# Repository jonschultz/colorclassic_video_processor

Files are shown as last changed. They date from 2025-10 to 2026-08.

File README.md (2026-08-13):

# colorclassic_video_processor
Project for the reverse-engineering of the Macintosh Color Classic's CRT video processor
# Color Classic Video Processor
#
colorclassic_video_processor is an ongoing reverse‑engineering project to recreate the functionality of the XC1186B video processor IC found on the Macintosh Color Classic analog board by designing a replacement PCB that is pin‑compatible with the XC1186B. The goal is not a circuit‑for‑circuit replica but a practical drop‑in replacement that reproduces the processor’s essential behavior (with some features intentionally simplified or omitted and the possibility of adding new capabilities). A major part of the design philosophy is to make use of discrete components in fully custom circuitry, rather than commercial ICs, as much as possible. This helps to ensure that exact behavior is very well understood and documented, while also avoiding future parts obsolescence. Development has progressed to the point where the vast majority of features have been implemented, enabling a Color Classic to generate all required CRT signals for 640×480 VGA operation on machines that were previously modded for that mode. The horizontal deflection pulse, vertical deflection sawtooth waveform, and RGB pre-amps are some of the major circuit subsystems that have been implemented. With little available documentation on the XC1186B itself, functionality had to be initially infered through a long process of signal measurement, route tracing, enabling/disabling various circuit sections, and reproduction of parts of the analog board's schematic. (See my latest partial analog board schematic [here](https://github.com/jonschultz/colorclassic_video_processor/blob/main/images/CC_analog_video_section_20260513A.pdf)). Much of that work is documented here, albeit most of it after the fact. As of July 2026, multiple revisions of PCBs with hand-assembled components have been tested, including earlier milled PCBs and later vendor-fabricated PCBs. The latest is v4.0.1, which includes minor improvements to the original v4 design, tested with rework applied. If you want to skip a lot of details and go directly to downloading the design and fabrication files, go [here](https://github.com/jonschultz/colorclassic_video_processor/blob/main/fabrication.md).<br><br>

## Current Capabilities (v4)
* Support for 640x480 resolution at 60Hz refresh and 800x600 resolution at 57Hz refresh on VGA-modded Color Classics, or the "standard" 512x384 resolution at 60Hz refresh. Other resolutions, horizontal and vertical frequencies are also likely to work, but haven't been tested.<br>
* Brightness and Contrast adjustment functional by way of MacOS software controls, such as through the "Screen" control panel. Contrast adjustments are also functional by way of the front bezel buttons.<br>
* Large dynamic range adjustment of individual RGB channel gain is available using on-board potentiometers.<br>
* All geometry adjustment functions by way of the Color Classic's analog board rear potentiometers are functional.<br>
* Many of the color adjustment functions by way of the Color Classic's analog board rear potentiometers are currently functional, except for "Green Gain" and "Blue Gain".<br>
* Very high bandwidth RGB preamps on-board, providing very sharp images and exceptional color reproduction.<br><br>

## A Word about Specs and Compatibility
* It's currently difficult to know exactly what voltages or signals are within tolerance for inputs and outputs of the XC1186B. I can only work based on what are assumed nominals generated/received by the Color Classic. However, my hope is that colorclassic_video_processor would also work with other Macintoshes that also use the XC1186B, but I haven't done any testing with those systems, nor measured any of their associated signals/voltages.<br>
* The XC1186B is supplied with 8V and 24V (the latter, albeit, with relatively high output impedance) from the Color Classic's analog board. Like much of the inner workings of the XC1186B, I'm not sure how it uses those supplies internally. The 8V is definitely required to run most, if not all, of the subcircuits. In colorclassic_video_processor, I make use of the 8V for all the supply power, and no use of the 24V. There are multiple reference and supply voltages that I internally derive from the 8V. I've tried to make the circuitry tolerant to some variation and noise on the 8V supply, but it's not completely agnostic to the precise supply voltage. Geometry will vary slightly over the range of at least a few hundred millivolts, which can, of course, be corrected with the usual adjustments. This might be a difference from the behavior of the XC1186B, but again, I'm not sure how its supply voltages are spec'ed. The design is certainly open to the possibility of simple changes that could accomodate a wider supply voltage range or different nominal, if those applications ever arise.<br>
* colorclassic_video_processor will draw from about 600mW to 800mW of power from the 8V supply under normal conditions. This can vary as a function of resolution, brightness, contrast, and other factors.<br>
* All of my testing has been on my "Mystic"-upgraded (performed by me) Color Classic, using an LC575 logic board with 32MB of RAM and 1MB of VRAM. The analog board was modified using the "VGA mod", though I've gone back and forth between the 68V and 84V B+ modifications in order to test both at different times. I've also made modifications to easily switch back and forth between the stock sense line configuration and the VGA configuration, allowing me to test 512x384 resolution to some extent. The vast majority of my testing has been at 640x480 resolution, 60Hz refresh, using 68V for the B+. Quite a lot of work in v4 has gone into supporting a range of resolutions and frequencies, some with more testing than others.<br><br>

## Coming Soon (maybe)
* Possible support for the "Green Gain" and "Blue Gain" analog board potentiometers.<br>
* VGA input and output capability.<br>
* Ability to swap between Contrast or Brightness association with front bezel controls using an on-board physical switch.<br>
* See [Future and Ongoing Work](future.md)<br><br>

#
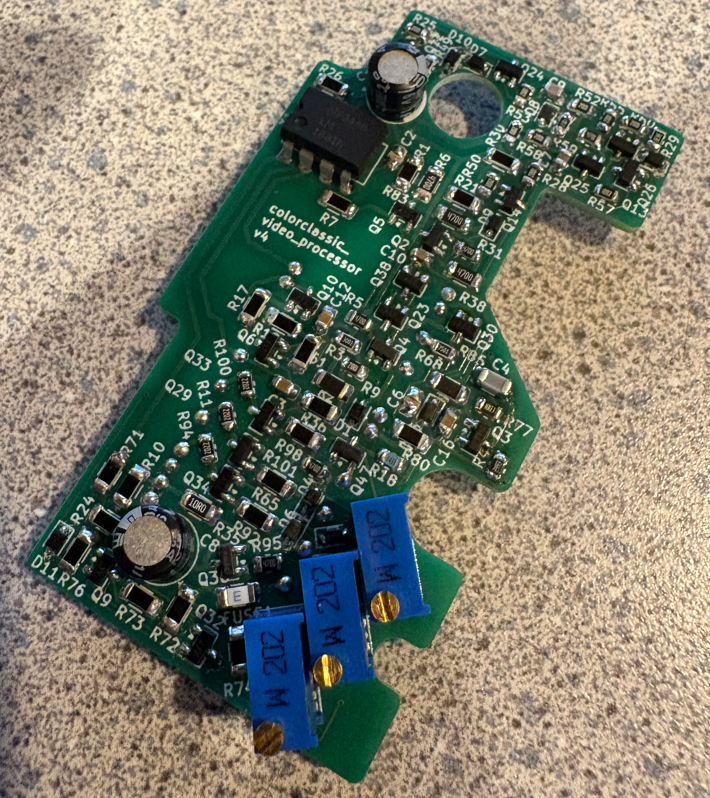
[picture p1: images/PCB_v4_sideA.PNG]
PCB1

<br>
Vendor-fabricated, hand-assembled PCBA. The outline of the PCB is quite unusual, in order maximize board area within the video "cage", while providing clearance to other nearby discrete components.
<br><br><br>
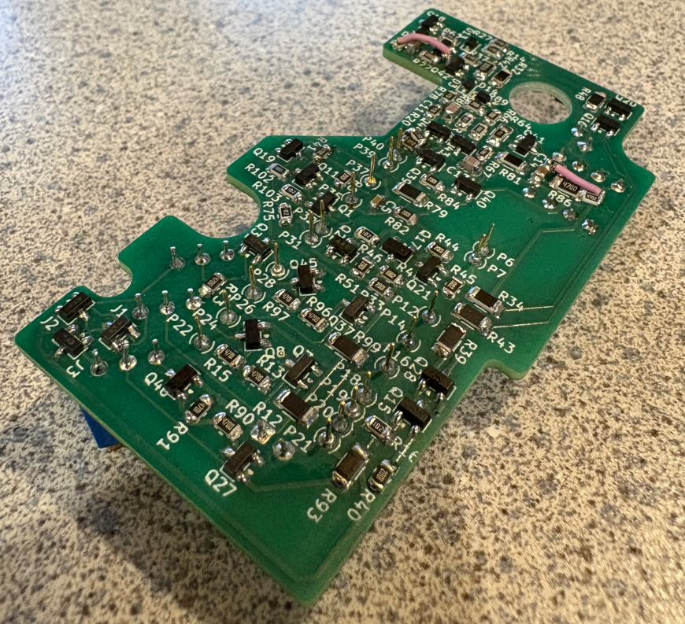
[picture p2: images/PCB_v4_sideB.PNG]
PCB2

<br>
Bottom side of the PCBA, showing pins and additional circuitry. Some rework is visible, bringing the design version from v4 to v4.0.1.
<br><br><br>
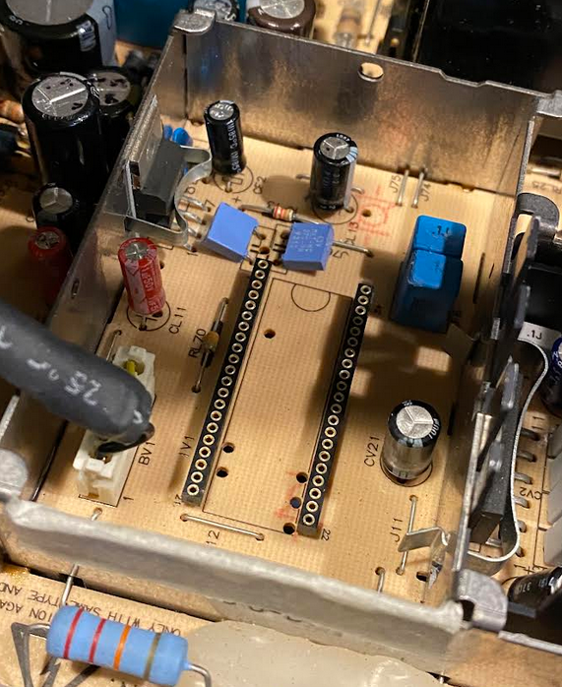
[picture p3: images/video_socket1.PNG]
socket1

<br>
The video "cage" on the analog board, showing the original XC1186B removed and 2x 21 pin sockets (Preci-dip 317-87-121-41-005101) installed for quick installation and removal of the custom PCBA.
<br><br><br>
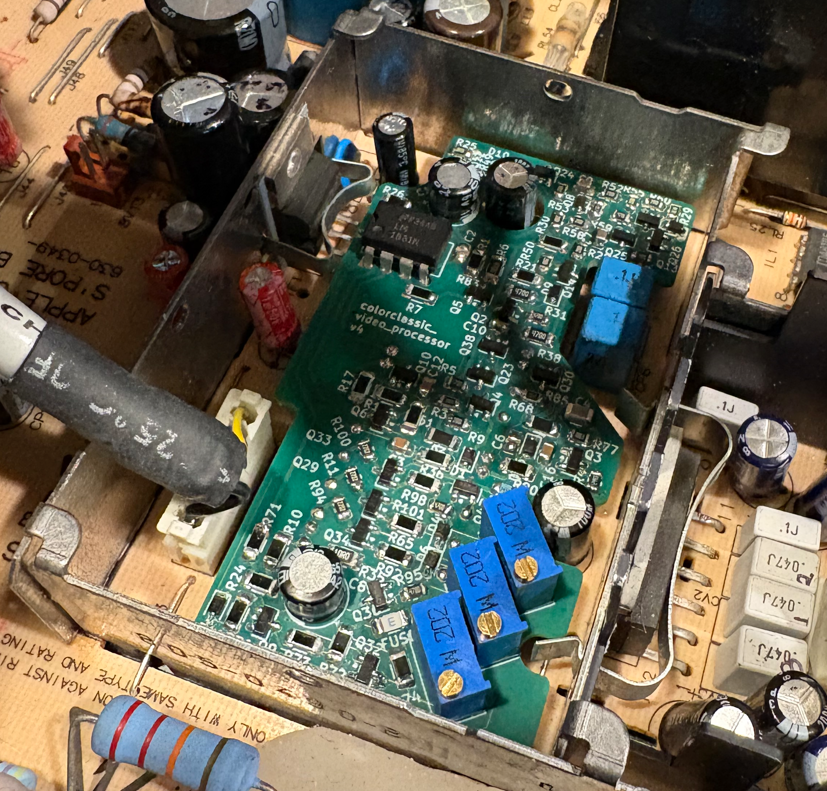
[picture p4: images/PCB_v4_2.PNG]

<br>
The v4 PCBA installed in the sockets.
<br><br><br>
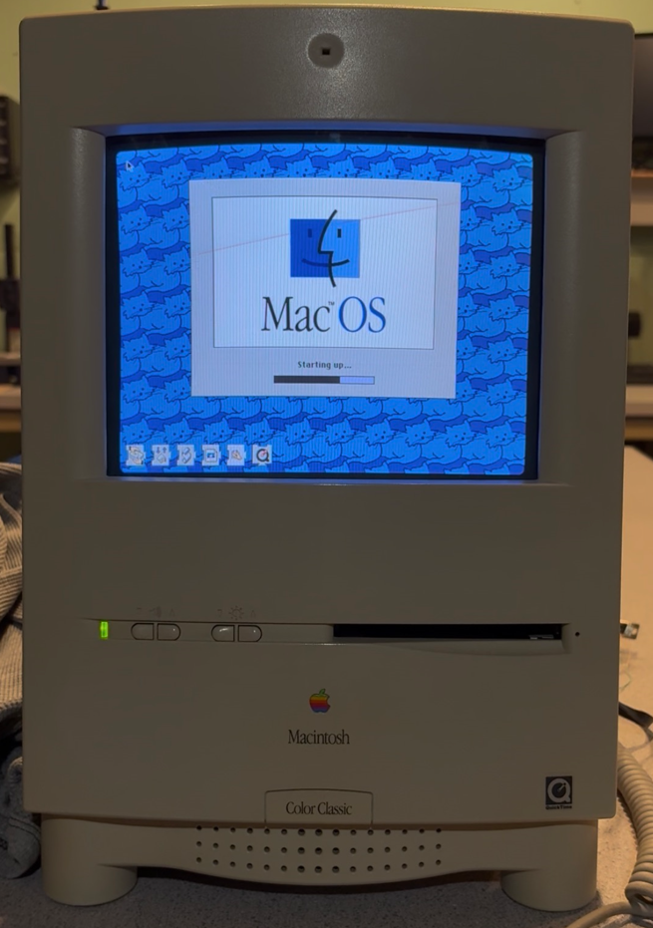
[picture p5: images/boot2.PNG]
boot

<br>
Running with the colorclassic_video_processor, during boot.
<br><br><br>
#
[Image Gallery](gallery.md)
<br>
[Main Schematic and Sub-Circuits](sub_circuits.md)
<br>
[Fabrication Files and Notes](fabrication.md)
<br>
[Installation and Setup](setup.md)
<br>
[Future and Ongoing Work](future.md)
<br>

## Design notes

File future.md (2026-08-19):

# Future and Ongoing Work
* In the spirit of providing more drop-in compatibility, if there is any outside interest in enabling the Blue Gain and Green Gain pots on the analog board (the only two that are currently non-functional with colorclassic_video_processor) I might work to implement it. I doubt that I would eliminate the gain pots that are on-board, since I personally think this is an upgrade due to the large dynamic range and 3-channel independent control. More likely, I would enable the Blue Gain and Green Gain pots to provide a little bit of fine control, in parallel with the full-range control of the onboard pots, similar to I've implemented Sub Contrast.<br><br>

## Development History
* 8/18/2026 - Working on layout of v4.2.0 with on-board connector for VGA output.<br><br>
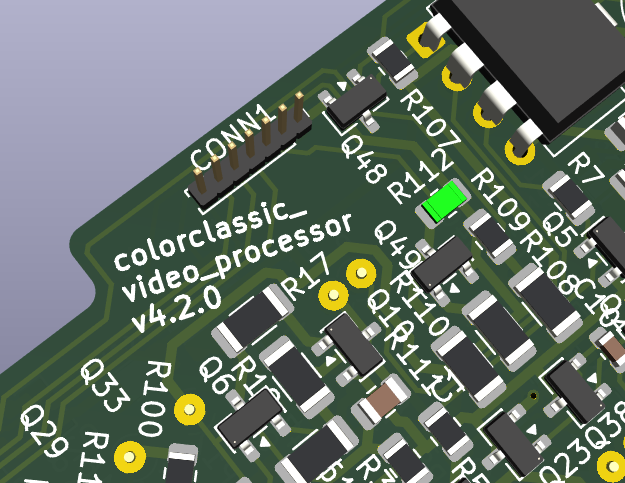
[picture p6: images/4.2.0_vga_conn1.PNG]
vga_conn1
<br><br>
* 8/12/2026 - Proof of concept for VGA output capability demonstrated with design mods and rework on a 4.0 PCB.<br><br>
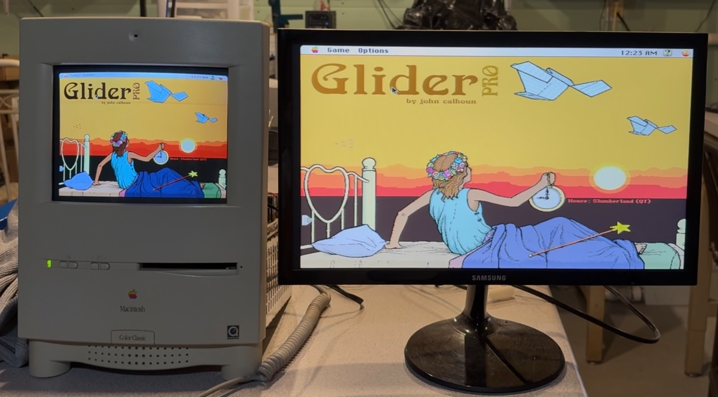
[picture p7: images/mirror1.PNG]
mirror1
<br><br>
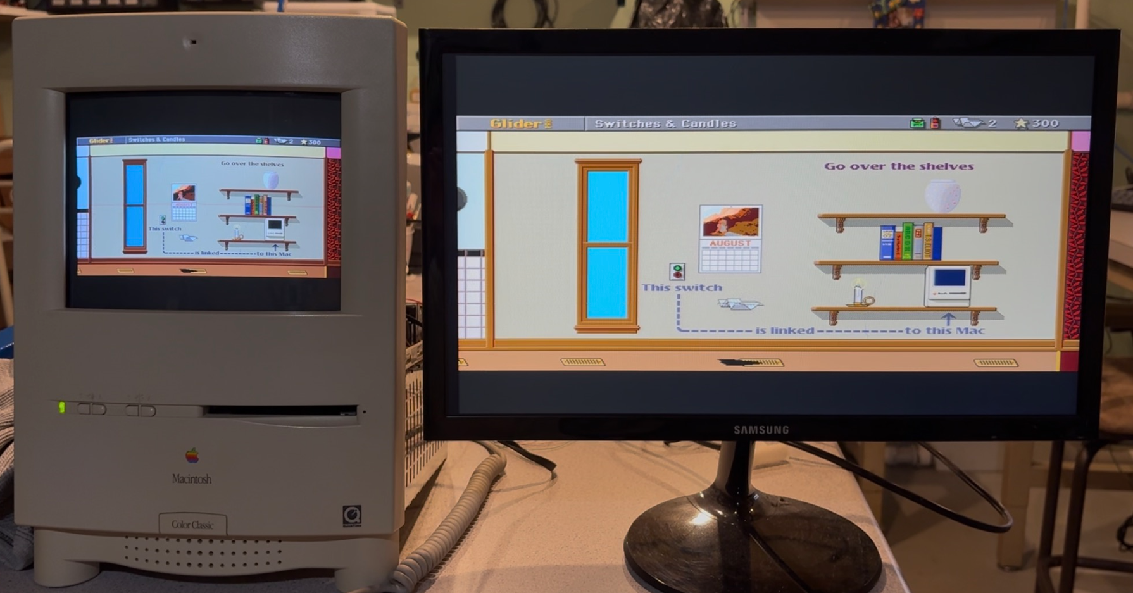
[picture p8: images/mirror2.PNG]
mirror2
<br><br>
* 7/26/2026 - Version 4.0.1 design released publicly.<br><br>
* 7/21/2026 - I've received the v4 PCBs from the fab, and I've got one assembled and running. Performance looks good and prety much identical to the reworked v3 prototype. However, I've already made some small changes to a few component values and some other minor changes in the horizontal section for further reduced temperature sensitivity. I plan to package up the KiCad files, BOM, and Gerbers + drill files for v4.0.1 and post them within the next few days. This will also mean that I'll need to clean up all the other sections of the repo to reflect the latest design. It's a lot of work, but it's coming.<br><br>
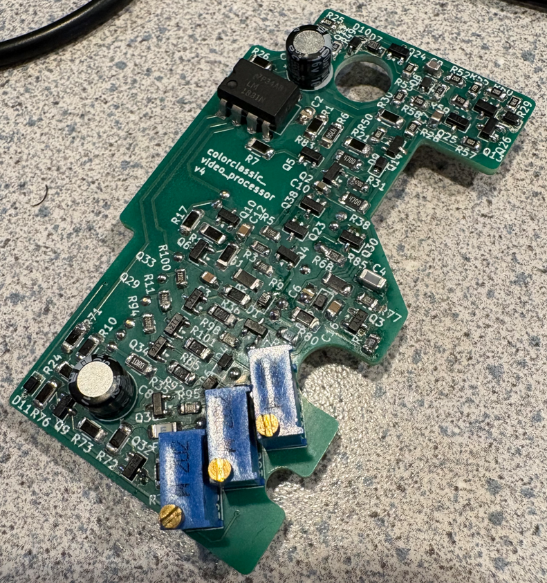
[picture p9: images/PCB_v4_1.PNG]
PCB_v4_1
<br><br>
PCB_v4_2<br><br>
* 7/3/2026 - Completed porting the v4 design to KiCad, and now in the process of getting PCBs made externally. After initial assembly and testing, I plan to update all the documentation and post output files for v4, including Gerbers for PCB fabrication. v4 features will include:<br><br>
    * Better support for various resolutions and timings by normalizing horizontal and vertical adjustment ranges accordingly.<br>
    * PLL-like horizontal timing synchronization for reduced drift and horizontal shift effects across a frame (such as due to pincushion correction). Eliminates the need for a special connection to the TDA8145.<br>
    * Eliminates the additional coarse vertical adjusment potentiometer.<br>
    * Cleaner routing using standard PCBA design rules.<br><br>
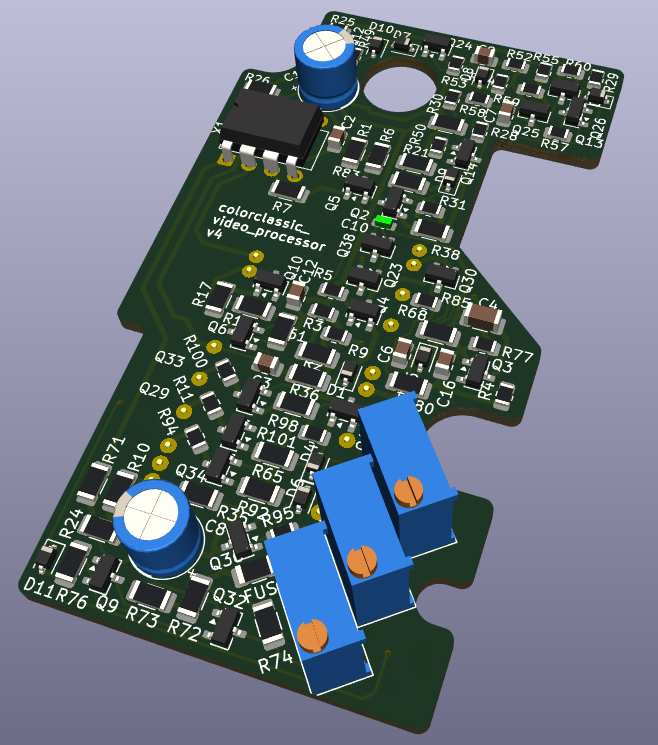
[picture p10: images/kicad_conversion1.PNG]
kicad
<br><br>
* 6/27/2026 - v4 design is complete and I'm in the process of converting the project over to KiCad. The next design and output files that I post here will hopefully be output files from KiCad for easy PCBA fabrication.<br><br>
* 6/20/2026 - Further improvements to the phase correction in the horizontal circuitry have been prototyped and are working well. It has improved capability to detect the horizontal frequency and scale certain signals accordingly, requiring even less adjustment when switching resolutions. I've also implemented similar scaling in the vertical circuitry, though there's still some work to be done there for v4.<br><br>
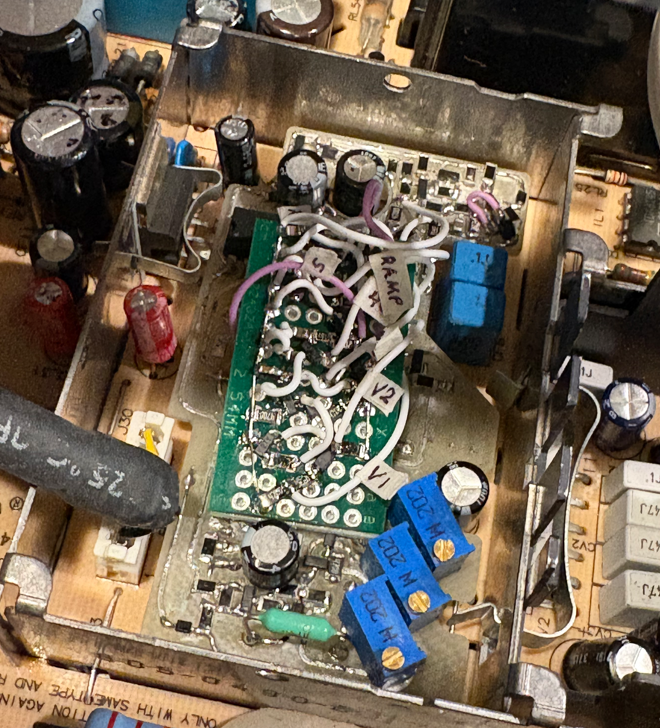
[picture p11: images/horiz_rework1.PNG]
rework
<br>
v3 PCBA with rework and additional proto-board to experiment with v4 changes.<br><br>
* 6/6/2026 - I've prototyped changes to the horizontal circuitry on v3 to measure and regulate the phase of the horizontal drive pulse relative to the flyback pulse, providing PLL-like functionality. This goes beyond even the function mentioned above, removing many of the horizontal shift drift effects. It also makes the system even more agnostic to various resolutions and associated horizontal frequencies, and eliminates the need for a signal from the TDA8145 for "warp compensation". I'm working on more testing and optimization. I hope to have a v4 layout done in the next couple of weeks.<br><br>
* As of 5/26/2026, I've been experimenting with design changes and rework of the published v3 design to change the horizontal drive timing architecture. I have it basically working with timing referenced to the current scanline's HSYNC pulse, while also controlling the duty cycle more accurately. This makes the system much more tolerant of changes to the horizontal frequency, enabling 512x384, 640x480, and 800x600, with only some adjustment of the Horizontal Shift ("HS") potentiometer.<br><br>

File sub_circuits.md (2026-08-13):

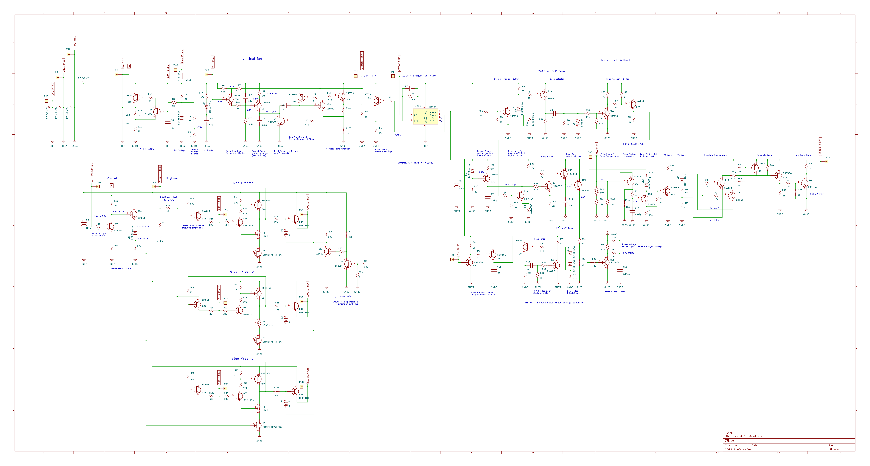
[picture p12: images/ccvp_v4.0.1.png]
schem_4.0.1

#
Change Log:
* 7/26/2026 - Updated to the v4 design (v4.0.1 design and output files provided as first release), including lots of improvements and a true EDA-based design using KiCad.<br><br>
* 5/24/2026 - Changed R54 value to 1k and changed D8 to Schottky. Both changes were required to achieve faster HSYNC edge detection at higher resolutions, with more support coming in the future.<br><br>
* 5/17/2026 - Updated some references to component values below. Clarified description of capabilities for RGB gain control.<br><br>
* 5/13/2026 - Update to schematic 20260513A. Change name of "Skew Compensation" to "Warp Compensation" and make it a standard section of the circuitry, now that it has been implemented in the latest revision. Incorporate SMMBFJ177LT1G JFETs into RGB preamps as part of dynamic gain for contrast adjustment. Add level shift circuit section for using the contrast adjustment voltage at Pin 19 to drive JFETs.<br><br>
* 4/5/2026 - Update to schematic 20260405A. Incorporates capacitive coupling between vertical deflection accumulator and amplifier and associated output-referenced clamp. Coarse adjustment pot for vertical size removed and replaced with fixed resistors. V1 of horizontal section changed to fixed voltage with Schottky diode. Ramp buffer converted to NPN follower for improved thermal stability (always far from saturation region). In RGB section, introduced output-referenced active clamp with simplified brightness supply. VHF/UHF BJTs incorporated into amps. Created unity-gain buffer section with pulldown for sync-tip insertion. Minor value tuning to accomodate reversion to original CC flyback (157-0146) and associated change of B+ from 84V to 68V.<br><br>

<br><br>
# General Notes
* Unless specificed for another particular component, any reference to a "Pin" position is with respect to the XC1186B's original pinout, and as such, the pinout of colorclassic_video_processor.<br><br>
* I've taken some effort to label components uniquely and clearly, but there's always the possibility for mistakes. The reference designator numbering is somewhat random, as automatic labeling was at play while the design evolved over time. Many components were deleted and new ones emerged, with numbers being recycled in a somewhat disorganized way.<br><br>
* A parts BOM is provided in the [Fabrication Files and Notes](fabrication.md) section. Some specific part numbers are provided in the schematic above, but many aren't. Some common parts, like resistors, will only be given rough specs and package type rather than a specific manufacturer's part number.<br><br>
* I've added a "Condsiderations" section for each circuit category below, mainly to help those interested in building on this design or making changes. These sections are intended to explain some of my design intent and some possibly important things about the CC's electronics in general. My understanding is certainly not 100% comprehensive, but I hope others find this information useful.<br><br>
<br><br>

# Horizontal Section
<br>
The high-level function of the horizontal section is to take the composite sync signal provided on the Color Classic analog board ("AB"), extract a horizontal sync signal, and then use that to generate the horizontal deflection pulse within the required range of duty cycle. The horizontal deflection pulse is used to ultimately pulse the horizontal output transistor on the AB.
<br><br>

## Signal Chain:
* The LM1881 IC is used to provide a DC-coupled, approx 0-6V composite sync ("CSYNC") signal, using the AB's AC-coupled CSYNC singal as input. The LM1881 provides other functions that will be described in later sections. But here, the "copy" of the CSYNC signal is useful as a low-ouptut impedance input to the horizontal circuitry. The CSYNC falling edge represents the start of a scanline.<br><br>
* CSYNC pulls a simple voltage regulator of two 3.3V Zener diodes to ground when high with a BJT inverter, conversely producing 6.6V at the falling edge.<br><br>
* The 6.6V pulse is buffered and drives a simple edge detector comprised of an RC network. A quickly decaying exponential pulse results (about 1μs in duration), independent of the duty cycle of the CSYNC input. This allows the circuity to generate all pulses nearly equally in amplitude and duration, whether the input pulse is at the start of the scanline or during the vertical sync period when the duty cycle is larger.<br><br>
* Two BJTs are used to "clean" and buffer the pulse into a more digital signal. In effect, this generates a horizontal sync ("HSYNC") signal.<br><br>
* Independently, a BJT current source (referenced to the 8V rail) linearly charges a 0.047uF accumulator capacitor to produce a linear voltage ramp.<br><br>
* The HSYNC pulse is then used to reset the accumulator to 1 Vbe (set by a biased diode D9) at the horizontal frequency at the start of every scanline. The resulting sawtooth waveform is buffered by an NPN BJT, with an output voltage between 0.6V and 4V.<br><br>
* Two reference voltages ("V1" and "V2") are generated through a complex timing network, which is new for v4, described further below. Threshold comparator BJTs are used to trigger switching when the accumulator sawtooth crosses the V1 and V2 voltages, corresponding to the falling and rising edges of the horizontal drive pulse that is ultimately provided as an output on Pin 32.<br><br>
* The switching of the threshold logic BJTs is inverted and buffered by another switching BJT. This signal is applied to Pin 32, which drives a MOSFET on the AB and ultimately drives the rest of the horizontal section. The timing of the rising edge of this final output pulse controls the phase of the horizontal scan in relation to all other signals (especially the video signals). This edge should occur about 28μs after the falling edge of CSYNC in order to have a well-centered image (at 31.5kHz horizontal scan frequency).<br><br>
* As mentioned above, the V1 and V2 voltages a generated by timing network that receives feedback from the flyback pulse on Pin 35. The flyback pulse first triggers the charging of C13. A separate circuit sub-section triggers off the previously described sawtooth waveform at roughly halfway through the scanline, using the peak value of the sawtooth for normalization (which can vary depending on image resolution and horizontal frequency). This section subsequently dicharges C13. The voltage on C13, therefore, provides a roughly 50% duty cycle digital pulse representing the phase relationship between the flyback pulse (representing the true start of a scanline) and a half-scanline delay from the horizontal sync pulse. Subsequent filtering to produce a "phase voltage" and comparison to a reference voltage provided by way of "HS" Pin 40 is used as an input to modulate "V2" (and the derived "V1"). In effect, the circuitry provides PLL-like timing feedback to maintain the phase relationship between the horizontal sync and the actual scanline start time. This automatically corrects for phase changes in the downstream horizontal deflection circuitry on a line-by-line basis, such as from width modulation handled by the TDA8145. As such, there is no need for other correction circuitry tied to the TDA8145, as was implemented in V3.
<br><br><br>

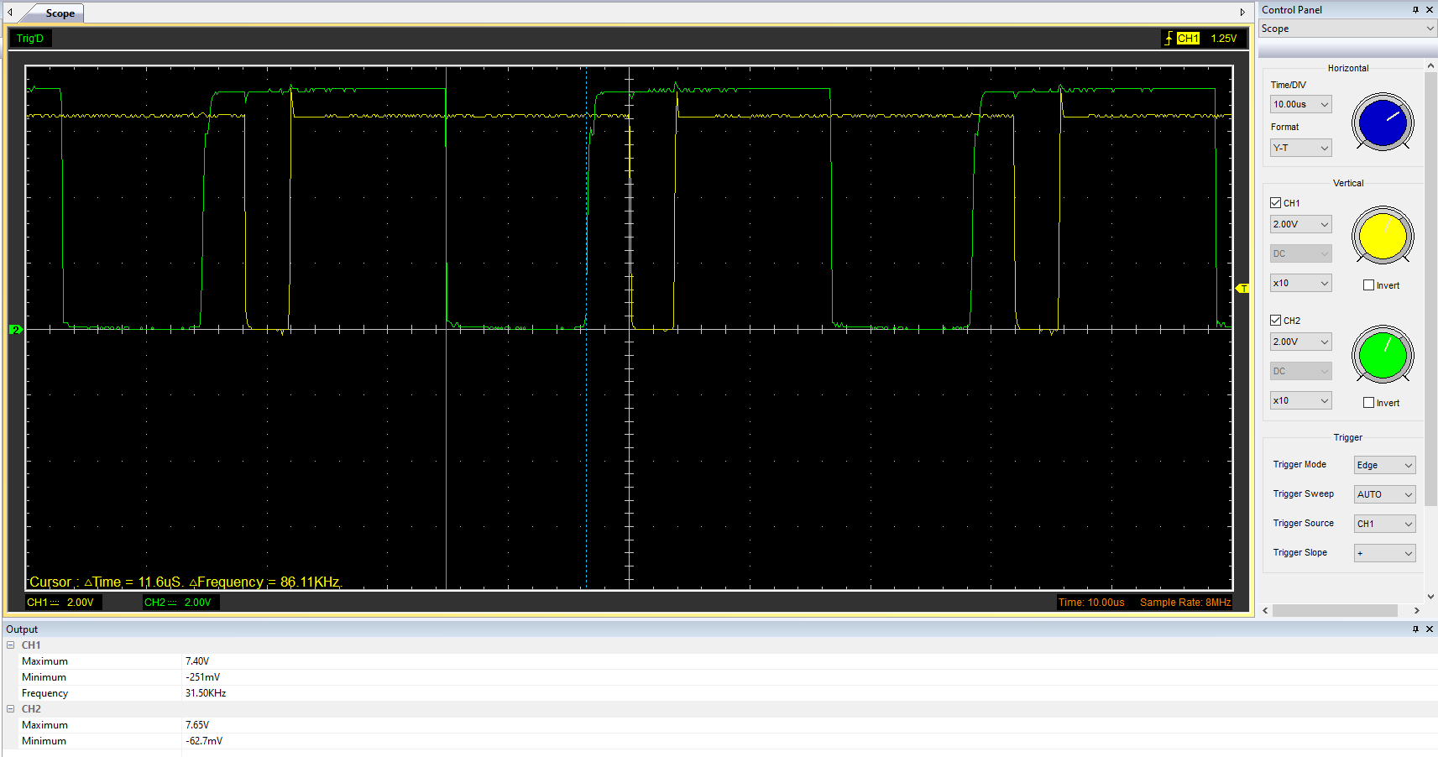
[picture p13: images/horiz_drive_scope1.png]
horiz

<br>
Scope shot showing the composite sync signal from pin 1 of the LM1881 (Channel 1) and the horizontal drive output signal (Channel 2) at Pin 32. The positive edge of the drive signal starts the cycle of tracing the next horizontal line as it drives the downstream circuitry on the AB. For a well centered image, this edge is roughly 28 microseconds after the negative edge of the previous composite sync pulse. The negative edge of the horizontal drive signal is less critical to the general timing, but is typically about 11-12 microseconds (as shown by the vertical cursors).
<br><br><br>

## Considerations:
* Like the other sub-circuits, the supply voltage is 8V from the Pin 22 position. This appears to be the main rail for powering the XCll86B, though there appear to be other supply voltages (more on that later). The grounding approach for all the sub-circuits is especially important for avoiding video artifacts. Through experimentation, I've found that associating all the horizontal circuitry with Pin 31 ground (#3 in my schematic) is best, which is physically closest to the pins associated with the horizontal section.<br><br>
* A lot of trial and error was employeed to make the timing stable, especially with respect to temperature. Use of accumulator capacitors with low temperature sensitivity is particularly important, as well as using a small voltage rise. The high linearity and lower temperature sensitivity outweigh any SNR benefit in this regime. I've also tried to match complementary pairs of BJTs or diode where possible to null the effects of junction voltage drift. A tiny bit of temperature sensitivity remains, which I've nulled with use of thermistor TH1 as part of the "HS" divider network.<br><br>
* A capacitor was originally connected in parallel with R45, in order to slow the discharge of the base voltage on Q21. The purpose of this was to avoid a short secondary pulse at the output when the sawtooth waveform falls sharply on the negative edge, switching the threshold circuitry in reverse order. These events happen on the time scale of a few microseconds, and as such, Q21 is discharges its base slowly enough without an additional discrete cap. The use of a relatively large resistance on R45 provides some discharge function (necessary to "reset" the circuitry quickly engough for the next cycle), but is slow enough to avoid generating the secondary pulse.<br><br>
* All BJTs used in this section are (S)S8050s (NPN) or (S)S8550s (PNP), unless otherwise noted. These are well matched BJTs that are reasonably fast for this application and have good gain. The final output transistor at Q22 requires a little more collector current handling, and I've opted for FMMT449. This part is also used for the discharge transistor for the accumulator.<br><br>
<br><br><br>

# Vertical Section
<br>
The vertical section's main function is to generate a sawtooth waveform that represents the beam displacement from the top of the display to the bottom, with the lowest voltage value representing the start of the scan at the top. This waveform drives the TDA8172, which is a sort of high-power opamp that directly drives the vertical deflection coil. Other sections of the AB also make use of the vertical deflection waveform, as discussed below. From probing the output of the original XC1186B, it was found that the vertical deflection sawtooth ranges from about 1.5V to 5.4V, with a high degree of linearity.
<br><br>

## Signal Chain:
* The LM1881 IC is used to generate a VSYNC signal, extracted from the AC-coupled CSYNC provided by the AB on the Pin 6 position.<br><br>
* Independently, a simple current source and a 0.47 microfarad accumulator capacitor generate a linear voltage rise of about 1V over a single 60 Hz refresh period. The exact current is adjustable by way of the AB's "VH" potentiometer, which is input on the Pin 39 position. VH forms a voltage divider with a 3.3V Zener-regulated supply, the output of which modulates a level shifter that drives the BJT current source.<br><br>
* The voltage on the accumulator capacitor is reset to ground with a BJT that's driven by the VSYNC signal as a triggering pulse. The video processor's 5V supply piggybacks off this regulator's Zener reference, and provides 5V output on the Pin 7 position.<br><br>
* The amplitude of the accumulator capacitor is intentionally kept low (1V as described above) in order to maintain high linearity of voltage with respect to time.<br><br>
* The final output sawtooth waveform requires a non-zero trough voltage of about 1.3V, though there is some tolerance on this. In order to achieve this voltage (corresponding to the "reset" state of the circuit) and produce a sufficient offset for the subsequent amplifier stage (described below), capacitive coupling between the accumulator and amplifier stage is employed with clamping. The clamping implementation measures the output of the amplifier stage during the trough with a BJT, using a simple 1.95V voltage divider (from the 3.3V supply) as the supply and reference voltage. This allows it to recharge the coupling cap to a relatively small voltage precisely, nulling out drift in the Vbe of the amplifier stage while requiring very little current from the 1.95V supply.<br><br>
* The accumulator's signal is then amplified by a dual-BJT feedback amplifier with a gain of 4x. The output is fed back to a comparator BJT Q30, which modulates the input to the accumulator current source to maintain a maximum peak value for the sawtooth waveform. This is referenced against a voltage derived from "VH" Pin 39, providing very stable waveform amplitude. The peak to peak values are approximately 1.3V to 5.4V, as required as input to the downstream circuitry of the AB, including the TDA8172.<br>
<br><br><br>

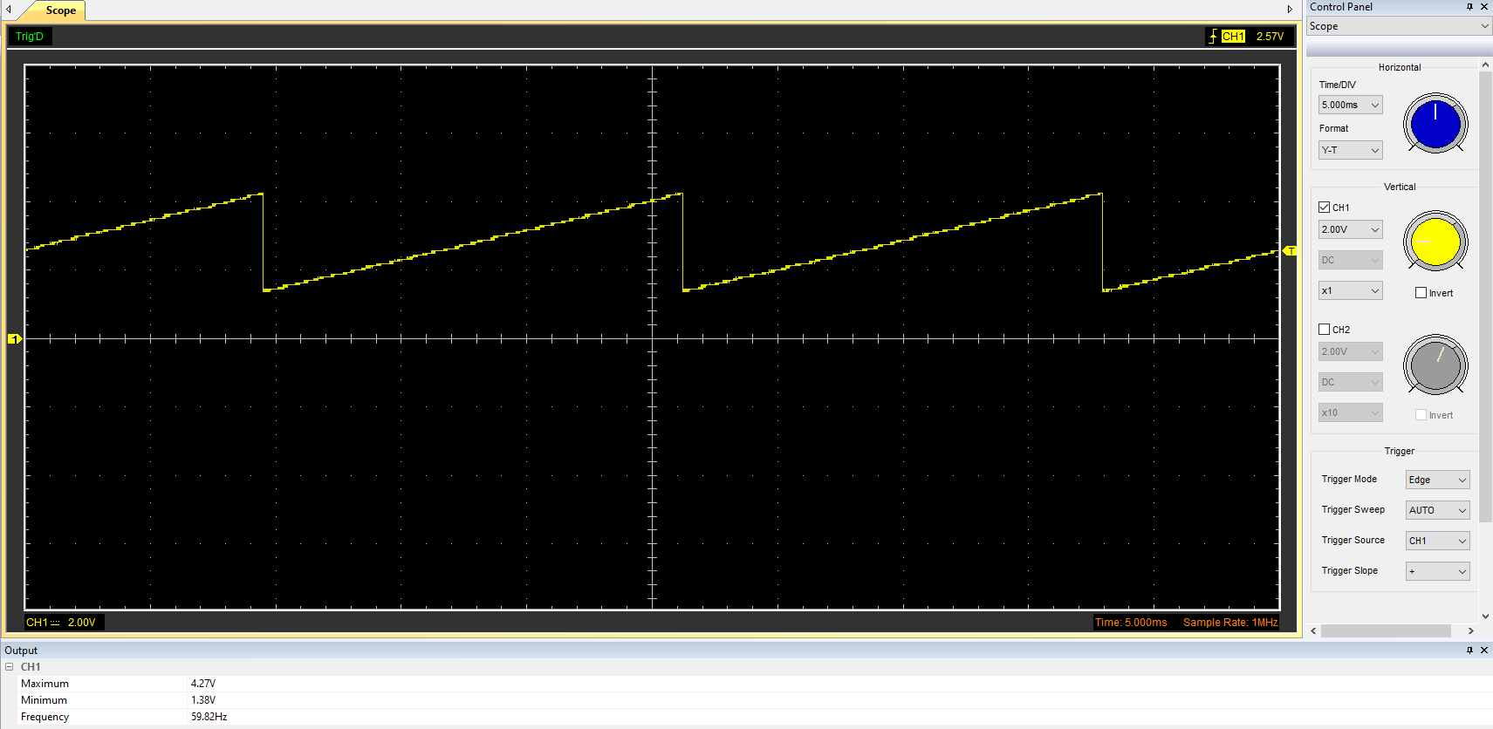
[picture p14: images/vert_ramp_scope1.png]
vert

<br>
Scope shot showing the vertical ramp signal generated on Pin 37.
<br><br><br>

## Considerations:
* As mentioned, keeping the accumulator amplitude low was important to maintain good linearity and temperature stability. D3 in the level shifter also helps in this regard by matching and nulling out much of the thermal drift in Vbe on Q3. Having a reliable and stable current source is important for this implementation.<br><br>
* The exact value of the trough of the vertical sawtooth waveform is not especially critical, as the output of TDA8172 is capacitively coupled to the vertical deflection coil, though it's important to not saturate the voltage on peak of the waveform. DC is restored separately at the TDA8172, and the vertical shift, "VS", potentiometer and associated circuitry on the AB contribute to this function. As such, VS still works as it normally would. As mentioned, other parts of the AB use the vertical sawtooth as a signal representing the vertical beam position, notably the TDA8145, which accepts it as input for pincushion correction (horizontal scaling as function of vertical position). Changes in the DC level ultimately result in modulation of the keystone geometry. The TDA8145 can account for this and add its own DC reference by way of the keystone correction potentiometer on the rear of the AB. A trough voltage of around 1.3V was empirically found to be suitable for all functions.<br><br>
* Like in the horizontal section, using the appropriate ground connections is important. I'm using a mix of Pin 31 and Pin 12 ground connections on the prototype PCB. It turned out to be a fortunate choice, as these two are nearly equivalent, being in very close connection on the AB and seemingly associated with the original XC1186B's vertical functions. Video artifacts can result if the Pin 21 ground is instead utilized in the vertical circuitry.<br><br>
* The 5V supply in the vertical section leverages the nearby 3.3V Zener supply as a reference, multiplying it (minus the Vbe of the input BJT) with a 2x gain to achieve ~5.4V. This was found to be slightly better performing that than a nominal 5.0V, possibly because the TDA8172 uses the 5V rail as a reference voltage. Shifting the reference slightly higher than the peak voltage of the vertical sawtooth waveform prevents the appearence of some geometry artifacts at the bottom of the vertical scan. The 5V rail is used in multiple locations throughout the video circuitry, so it's an important supply. Stability is especially important for the TDA8172, as fast fluctuations result in a visible "bounce" in the vertical size of the image as the TDA8172 amplifier settles to a new equilibrium. In an earlier design, small changes in the 3.3V supply induced by fluctuations in the 8V rail caused significant bounce, as the quick step-like changes in the 5V rail create ringing in the TDA8172 ouptut. Quick changes in image brightness are especially prone to causing such fluctuations in the 8V rail. A simple fix was to decouple the 5V supply from the 3.3V reference with a long-time constant RC filter. Here, a 22k resistor and 10uF capacitor help significant to reduce the slew rate of the 5V output in response to step changes in the 3.3V reference, allowing the TDA8172 to equilibrate faster than the change in reference voltage. Fortunately, the actual DC value of the 5V rail plays a much less significant role in the TDA8172 output, making it tolerant to such slow but stable changes.<br><br>
* Like in the horizontal section, all transistors are either (S)S8050s or (S)S8550s, except in case of Q4, which requires especially high collector current capability for discharge. Again, I've opted for FMMT449.<br>
<br><br><br>

# RGB Preamp Section
<br>
Another major function of the XC1186B is to take the low-amplitude, capacitively-coupled RGB signals from the logic board (brought in on connector BV1), add offset for brightness control, amplify them (incorporating contrast control), add sync-tips, and deliver the output to the downstream cathode amplifiers. Interaction with the other sub-functions of XC1186B seems to be fairly limited, with the exception of sync-tip insertion driven by the timing of the sync signals. My implementation is fairly straightforward, making use of dual-transistor class-A amplifiers for each color channel, though the choice of biasing resistors and BJTs was important to provide high bandwidth for crisp image production. There are some nuances in the clamping/brightness circuitry, as well as the sync-tip insertion circuitry, discussed below.
<br><br>

## Signal Chain:
* RGB signals are brought in from Pins 14,16,18, with capacitive coupling and 75Ohm termination provided right on the AB prior to connections at the XC1186B pins. These connections are made to both the amplifier stage and to brightness-control/clamp circuitry, described below.<br><br>
* The amplifier stage for each channel is comprised of an NPN input BJT and PNP output BJT. These are high-speed VHF/UHF BJTs, part numbers MMBTH10L and MMBTH81. A 4.7K pull-up resistor at the base-emitter connection of the PNP greatly improves speed (reducing image smear) by discharging the PNP's base quickly on falling signals, at the cost of a small reduction in the effective gain. The resistor divider on the output, which currently includes 2k trimmer pots on the PCB, determines the amplifier gain (effectively, the image contrast), with a range of about 1x to 5x.<br><br>
* The output of the amplifier stage feeds back to a PNP BJT for active clamping of the capacitively coupled input, as mentioned above. The BJT effectitvely compares the minimum output value (during black-level display) against a reference voltage that also serves as a supply for the clamp. The reference voltage is a divided-down version of the brightness signal itself, provided on Pin 20, with a range of about 1.9V to 2.7V. The brightness signal can be modulated by the logic board, via the Color Classic's brightness control in the "Screen" Control Panel, in addition to other software-controlled interfaces. By measuring against the amplifier output, the clamping circuitry charges the coupling cap to the appropriate level on each scanline, independent of the amplifier gain or other offsets. It's especially good at nulling the drift in the input BJT's Vbe offset and its associated amplified offset, which can be quite large. Charging the coupling cap requires very little current, as as such, the upstream brightness supply does not require additional buffering.<br><br>
* The amplifier output is "lightly" coupled to the downstream circuitry by way of a 470 Ohm resistor. Downstream of it is another MMBTH10L, acting as a simple unity-gain buffer. The base input of this buffer also serves as a node to pull down during sync-tip insertion, without excessively loading or affecting the amplifier stage. The sync-tips are zero-voltage pulses that match the timing and duration of the CSYNC signal, and are used in the downstream cathode drive circuitry for DC restoration. In effect, they serve as a fixed reference voltage to the black level set by the brightness/clamp circuitry. A cascade of two BJT inverters is used to condition the CSYNC signal from the LM1881, which pulls down the unity-gain buffer's base low during the sync pulse period. A single set of inverters services all three color channels, isolating the output of each associated buffer through individual Schottky diodes.<br>
<br><br><br>

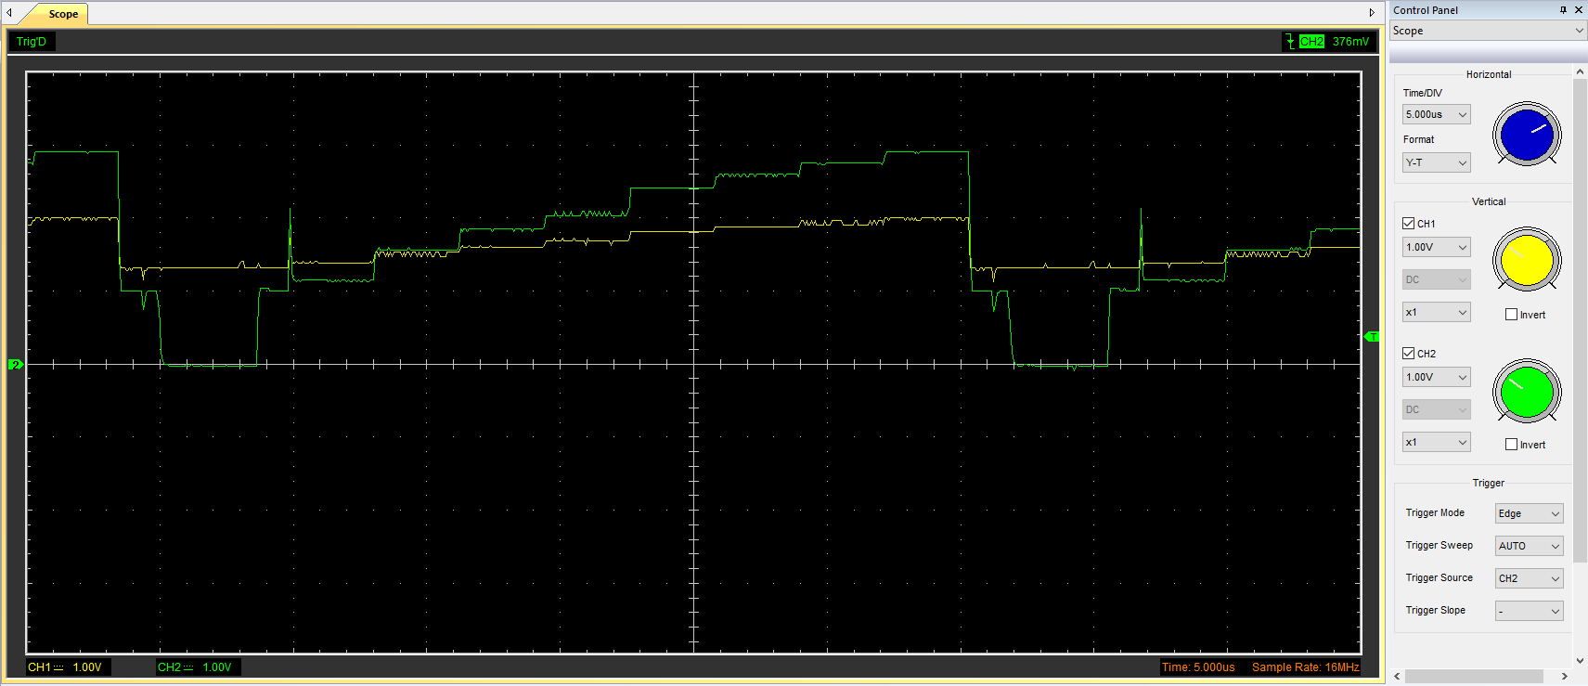
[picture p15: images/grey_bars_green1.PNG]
bars

<br>
Scope shot showing green channel input (Channel 1) at Pin 16 and green channel output (Channel 2) at Pin 26, while displaying a grey bar pattern and with brightness and gain (contrast) optimized for picture quality. The signal input has a range from about 1.3V to 2.0V, and the output is from about 1.0 (black level) to 2.9V, representing a gain of about 2.7x. Note the sync tips in the output signal that fall to 0V.
<br><br><br>

## Considerations:
* The 2k pots on the PCB offer direct control of the image contrast for each channel, but are not ideal solutions for a few reason. One is that they are not readily accessible with the RF cage in place, making casual fine adjustment impractical. Another problem is that the gain range is quite large, and it might be initially difficult to find the ideal contrast (in conjunction with optimal brightness, G2 setting, background, etc). In practice, using 2.8x as a starting gain value seems about optimal (with ".._POT_LO" equal to about 450 to 600 Ohms). See the "Installation and Setup" section for more details. While there is an overall gain control that is adjustable thorugh the Sub Contrast pot on the rear of the AB and through the Screen control panel, the Green Gain and Blue Gain controls on the rear of the AB are not yet functional. These are currently (with the Version 4 design) the only two rear controls that are non-functional.<br><br>
* The value of the coupling resistors R23, R95, and R101 between the amplifier stage and the buffer stage, was chosen as a sort of compromise. Larger values allow the sync-tip insertion circuity to more easily pull down the signal without loading the amplifier's output, but it would create a significant voltage drop between the two stages. The output of the entire RGB section drives 330 Ohm termination resistors (RV7, RV8, and RV9 on the AB), requiring up to about 13mA of current for bright parts of the image. Assuming the current into the buffer stage is about 1% of that, the 470 Ohm coupling resistor has about 63mV of voltage drop. This is not an insignficant drop as it is, and increasing the resistor's value would only add further signal attentuation. However, smaller values would present more of a current load during sync-tip insertion, loading the amplifier while possibly affecting the clamping circuitry.<br><br>
* Schottky diodes were chosen for the isolation of the sync-tip pulldown due to their low forward voltage-drop. This brings the sync-tip level very close to zero, but not quite. Other implementations could provide an improvement, but with higher part count or complexity, such as by utilizing individual pulldown BJTs (Q32) for each channel. Another consideration for the use of Schottkys is that, while they are quite fast, they do have a small capacitance that requires discharge to fully turn them off. The 22k resistor at R74 was found to be optimal to bring the Schottkys' cathodes high after each sync-tip without excessively loading Q32.<br><br>
* In general, the RBG circuitry is fairly sensitive to biasing and particular values of components. The bandwidth needs to be quite high (~100 MHz or higher), requiring fast BJTs and quick charge/discharge of parasitic capacitances. Signal cleanliness is also extremely important, including proper grounding and use of the specified AB ground pins. Generally speaking, any artifacts in the RBG signals are readily visible in the displayed image. A lot of trial and error and analysis of the RGB circuitry has been done to optimize performance. Qualitativley, I think my pre-amp design is quite good, possibly providing better performance and higher bandwidth than those of the XC1186B.<br>
<br><br><br>

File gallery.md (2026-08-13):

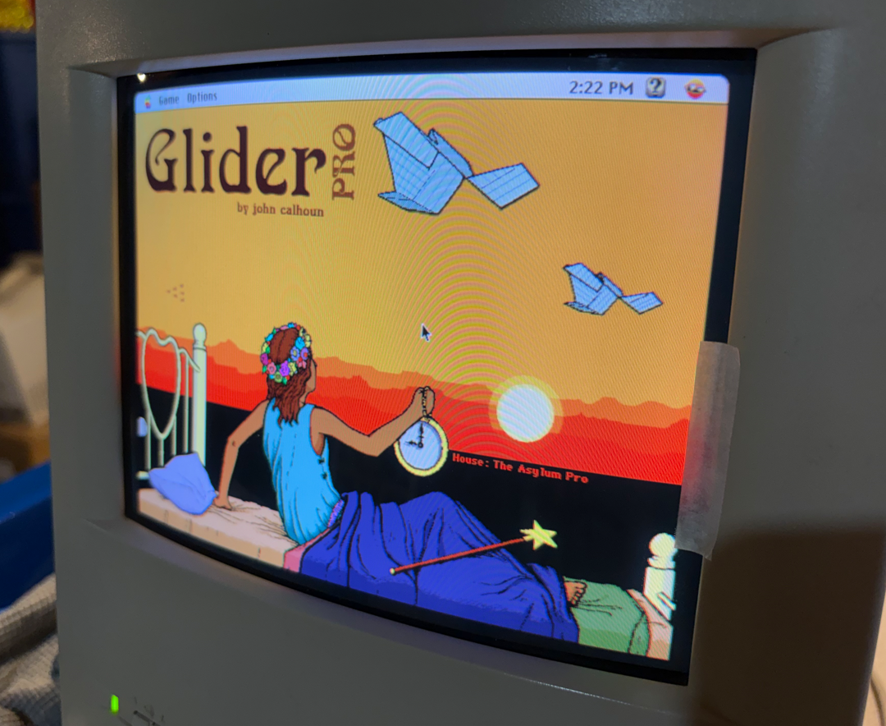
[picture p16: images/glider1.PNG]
glider1

<br>
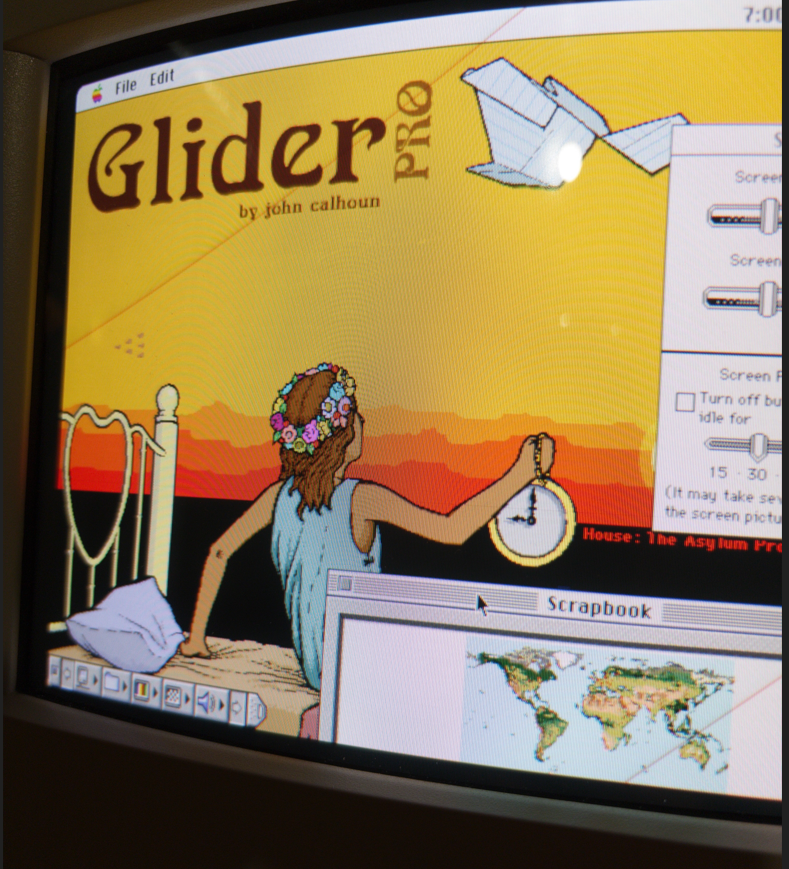
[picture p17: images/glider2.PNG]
glider2

<br>
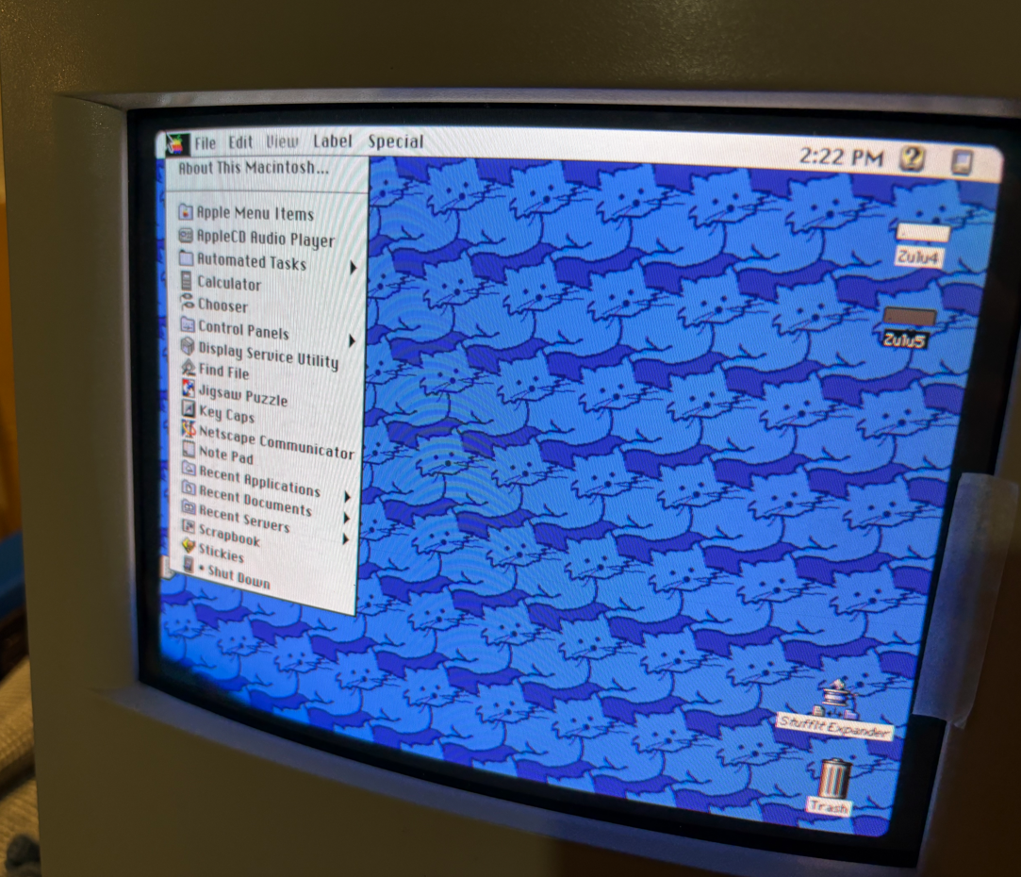
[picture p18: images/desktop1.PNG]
desktop

<br>
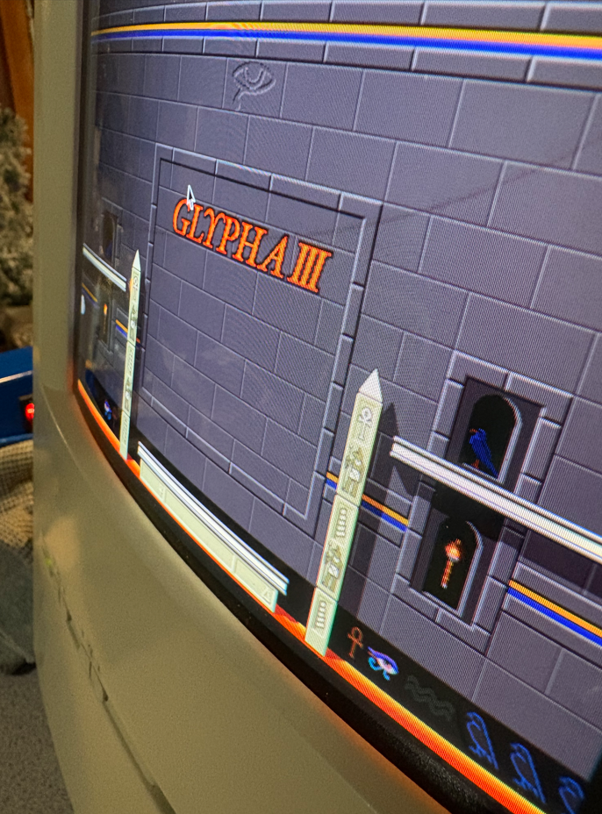
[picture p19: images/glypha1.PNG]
glypha

<br>
<br>
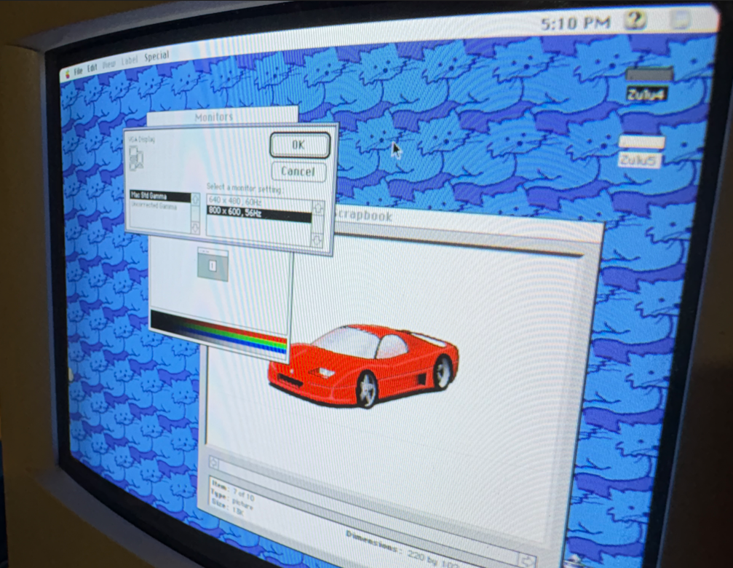
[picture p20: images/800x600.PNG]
800x600

<br>
800x600 resolution, using the VGA mod, in the 84V B+ configuration.
<br>

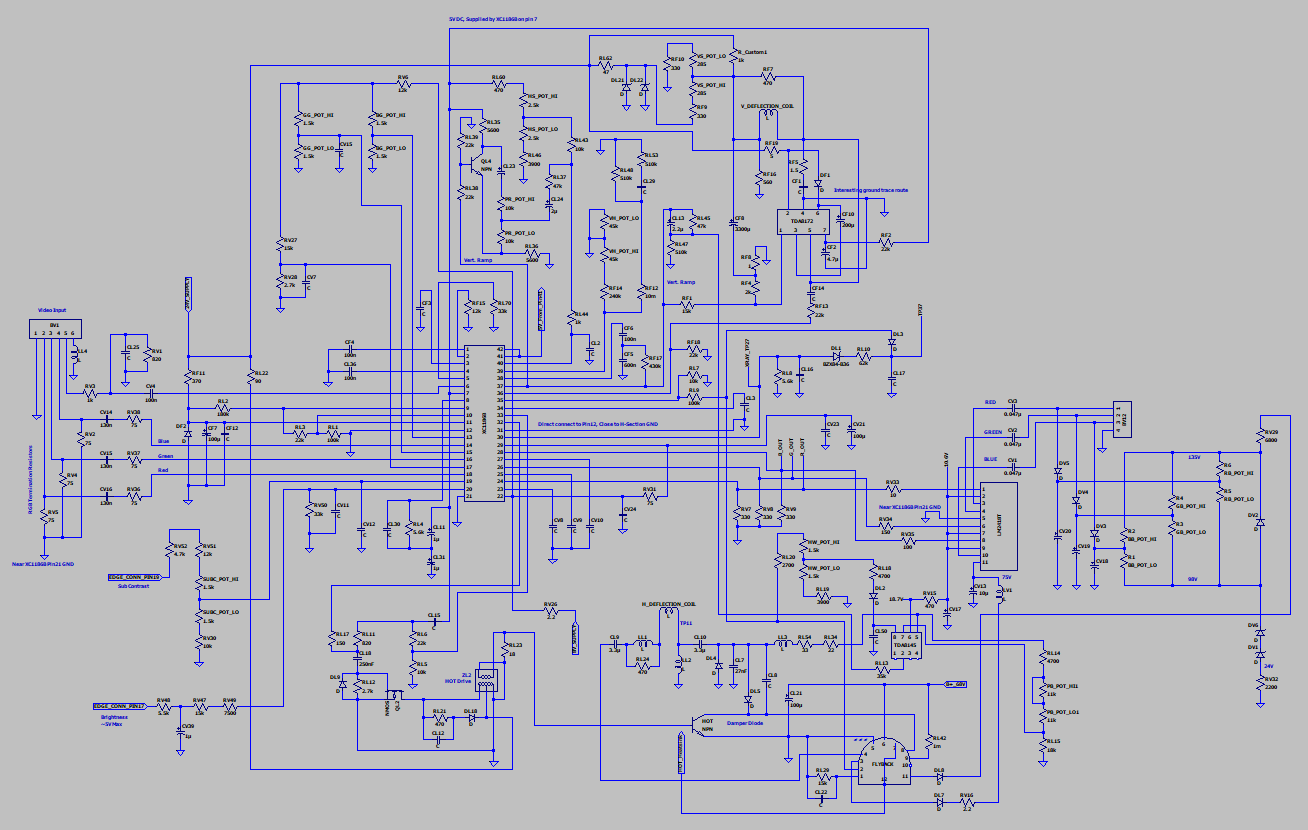
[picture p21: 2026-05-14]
images/CC_analog_video_section_20260513A.PNG

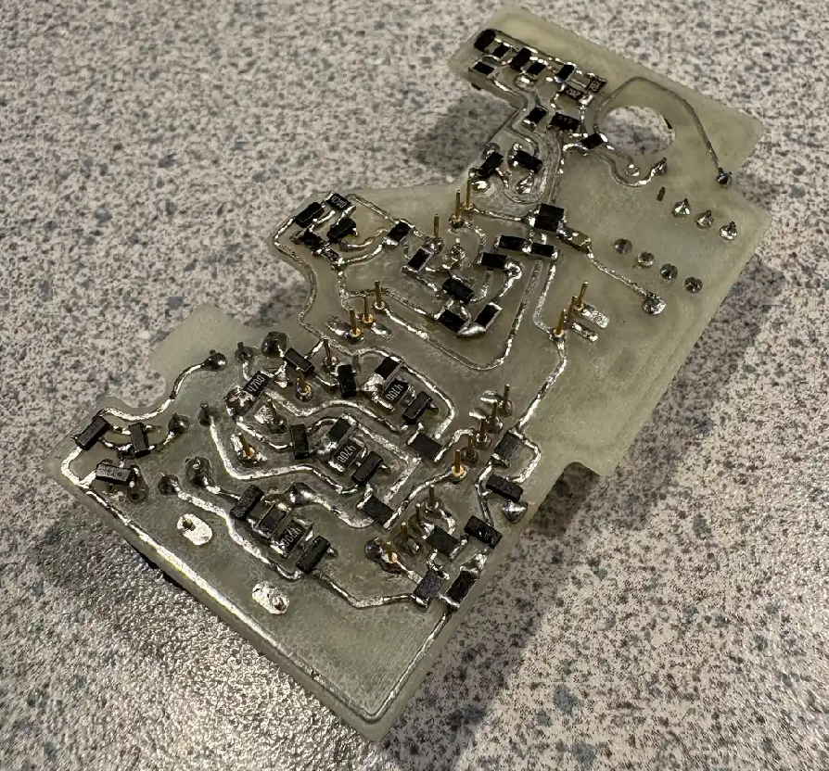
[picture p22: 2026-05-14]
images/PCB_sideB.PNG

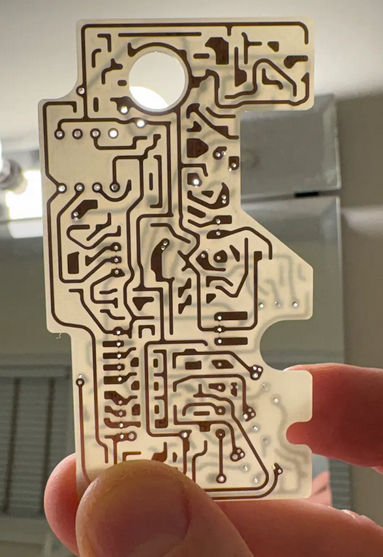
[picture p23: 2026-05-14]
images/bare_board1.PNG

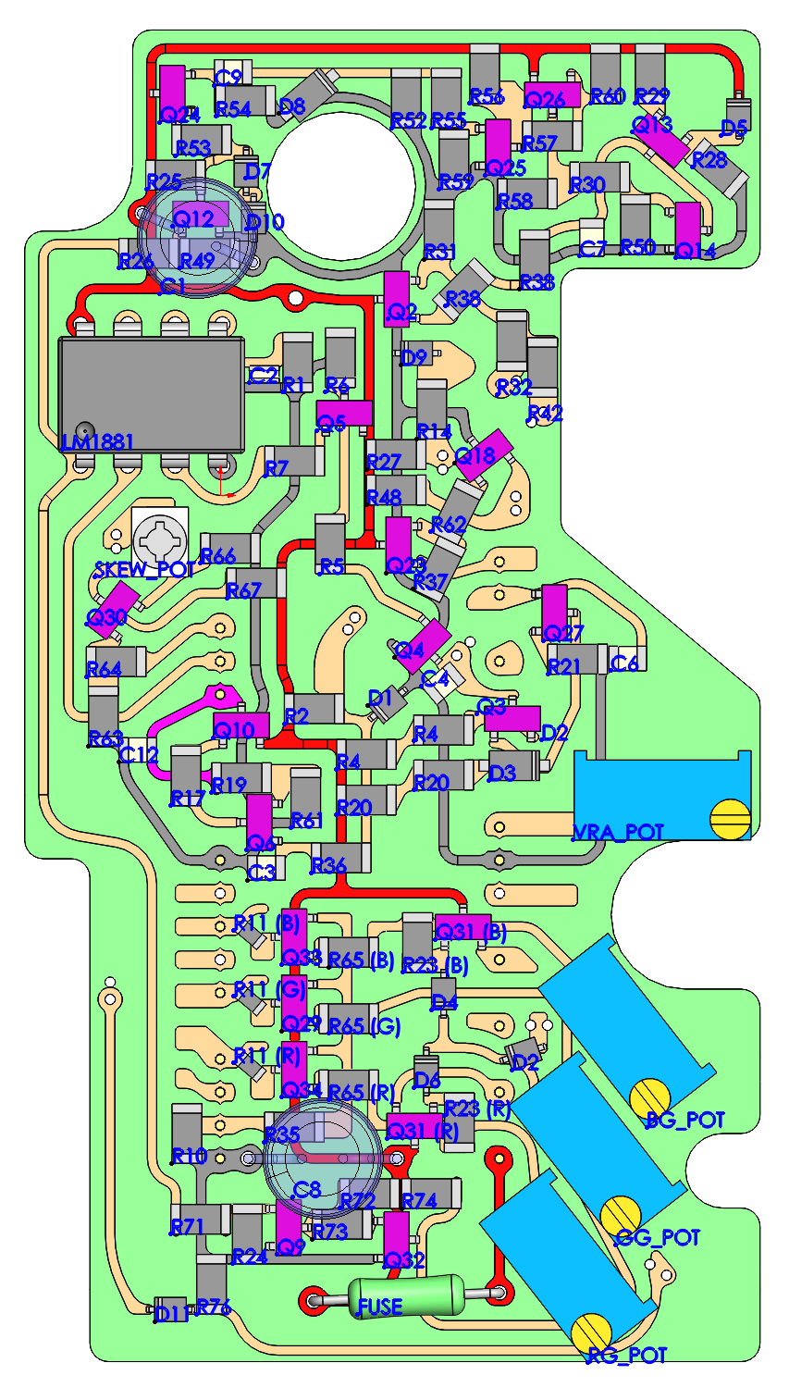
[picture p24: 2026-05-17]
images/video_integrated_PCBA3_top.PNG

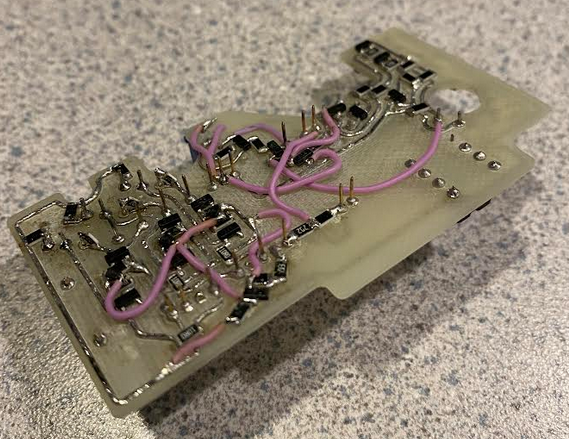
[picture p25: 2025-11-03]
images/pcb2.PNG

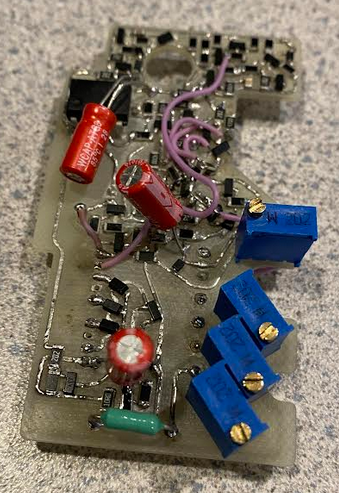
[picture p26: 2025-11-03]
images/pcb1.PNG

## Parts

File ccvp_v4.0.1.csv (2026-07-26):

Reference | Qty | Value | Footprint | Datasheet | MPN
BG_POT1,GG_POT1,RG_POT1 | 3 | 2k | Potentiometer_THT:Potentiometer_Bourns_3296W_Vertical | https://www.bourns.com/docs/product-datasheets/3296.pdf
C1,C8 | 2 | 100µ | Capacitor_THT:CP_Radial_D6.3mm_P2.50mm | https://www.mouser.com/catalog/specsheets/Kemet_09242021_ES5107M016AE1EA.pdf | ES5107M016AE1EA
C2,C6 | 2 | 0.1µ | Capacitor_SMD:C_0805_2012Metric | https://datasheets.kyocera-avx.com/cx5r.pdf | 0805YD104KAT2A
C3,C12,C16 | 3 | 10µ | Capacitor_SMD:C_0805_2012Metric | https://weblib.samsungsem.com/mlcc/mlcc-ec-data-sheet.do?partNumber=CL21B106KOQNNN | CL21B106KOQNNNG
C4 | 1 | 0.47µ | Capacitor_SMD:C_1206_3216Metric | https://www.mouser.com/datasheet/3/76/2/GRM31C5C1E474JE01_01A.pdf | GRM31C5C1E474JE01L
C5,C10 | 2 | 1µ | Capacitor_SMD:C_0603_1608Metric | https://weblib.samsungsem.com/mlcc/mlcc-ec-data-sheet.do?partNumber=CL10A105KA8NNN | CL10A105KA8NNNL
C7,C14,C15 | 3 | 0.047µ | Capacitor_SMD:C_0805_2012Metric | https://www.mouser.com/datasheet/3/508/1/KEM_C1091_C0G_ESD.pdf | C0805C473K3GECAUTO7210
C9,C11,C13 | 3 | 1n | Capacitor_SMD:C_0805_2012Metric | https://weblib.samsungsem.com/mlcc/mlcc-ec-data-sheet.do?partNumber=CL21C102JCFNNN | CL21C102JCFNNNE
D1,D5,D7,D10,D11 | 5 | BZX384xxxx | Diode_SMD:D_SOD-323 | https://www.vishay.com/docs/85764/bzx384.pdf
D2,D4,D6,D8 | 4 | BAT54H | Diode_SMD:D_SOD-323 | https://www.onsemi.com/pdf/datasheet/bat54ht1-d.pdf
D3,D9,D12,D13,D14,D15 | 6 | 1N4148WS | Diode_SMD:D_SOD-323 | https://www.vishay.com/docs/85751/1n4148ws.pdf
FUSE1 | 1 | C1F 250 | Fuse:Fuse_1206_3216Metric | https://www.belfuse.com/media/datasheets/products/circuit-protection/ds-cp-c1f-series.pdf | C1F 250
J1,J2,J3 | 3 | SMMBFJ177LT1G | Package_TO_SOT_SMD:SOT-23 | https://www.onsemi.com/pdf/datasheet/mmbfj177lt1-d.pdf
P6,P7,P12,P14,P16,P18,P19,P20,P21,P22,P24,P26,P28,P31,P32,P35,P37,P39,P40 | 19 | Mill-Max_3121-2-00-15-00-00-08-0 | custom1_footprint:Pin_D0.43mm_L3.99mm | https://4donline.ihs.com/images/VipMasterIC/IC/MMMC/MMMC-S-A0002810078/MMMC-S-A0002812117-1.pdf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
Q1,Q3,Q5,Q10,Q13,Q17,Q18,Q19,Q21,Q26,Q29,Q30,Q33,Q34,Q40,Q42,Q44 | 17 | SS8550 | Package_TO_SOT_SMD:SOT-23 | http://www.secosgmbh.com/datasheet/products/SSMPTransistor/SOT-23/SS8550.pdf
Q2,Q6,Q9,Q11,Q12,Q15,Q16,Q20,Q23,Q24,Q25,Q28,Q32,Q35,Q38,Q39,Q41,Q43 | 18 | SS8050 | Package_TO_SOT_SMD:SOT-23 | http://www.secosgmbh.com/datasheet/products/SSMPTransistor/SOT-23/SS8050.pdf
Q4,Q14,Q22 | 3 | FMMT449 | Package_TO_SOT_SMD:SOT-23 | https://www.mouser.com/datasheet/3/175/1/FMMT449.pdf
Q7,Q27,Q31,Q36,Q37,Q47 | 6 | MMBTH10L | Package_TO_SOT_SMD:SOT-23 | https://www.onsemi.com/pdf/datasheet/mmbth10lt1-d.pdf
Q8,Q45,Q46 | 3 | MMBTH81 | Package_TO_SOT_SMD:SOT-23 | https://www.onsemi.com/download/data-sheet/pdf/mmbth81-d.pdf
R1 | 1 | 200k | Resistor_SMD:R_1206_3216Metric
R2,R43,R48,R68,R79 | 5 | 1k | Resistor_SMD:R_1206_3216Metric
R3,R87,R102 | 3 | 3k | Resistor_SMD:R_0805_2012Metric
R4 | 1 | 249k | Resistor_SMD:R_0805_2012Metric
R5,R13,R14,R23,R27,R31,R37,R41,R90,R95,R96,R101 | 12 | 470 | Resistor_SMD:R_0805_2012Metric
R6,R38,R42,R83,R86 | 5 | 470 | Resistor_SMD:R_1206_3216Metric
R7,R17,R19,R24,R26,R32,R56,R61,R73,R76 | 10 | 2k | Resistor_SMD:R_1206_3216Metric
R8,R9,R25,R28,R30,R33,R40,R44,R50,R51,R52,R58,R60,R66,R82,R84,R89 | 17 | 2k | Resistor_SMD:R_0805_2012Metric
R10,R36,R65,R72,R74,R92,R98 | 7 | 22k | Resistor_SMD:R_1206_3216Metric
R11,R22,R94,R100 | 4 | 22k | Resistor_SMD:R_0805_2012Metric
R12,R93,R99 | 3 | 200 | Resistor_SMD:R_1206_3216Metric
R15,R20,R59,R78,R91,R97 | 6 | 4.7k | Resistor_SMD:R_0805_2012Metric
R16,R46,R49,R54,R75,R88,R103 | 7 | 1k | Resistor_SMD:R_0805_2012Metric
R18 | 1 | 143k | Resistor_SMD:R_0805_2012Metric
R21,R71,R81 | 3 | 10k | Resistor_SMD:R_1206_3216Metric
R29 | 1 | 383 | Resistor_SMD:R_0805_2012Metric
R34 | 1 | 4.7k | Resistor_SMD:R_1206_3216Metric
R35 | 1 | 10 | Resistor_SMD:R_1206_3216Metric
R39 | 1 | 3k | Resistor_SMD:R_1206_3216Metric
R45,R47,R53,R55,R57,R105 | 6 | 10k | Resistor_SMD:R_0805_2012Metric
R62,R63 | 2 | 15k | Resistor_SMD:R_0805_2012Metric
R64 | 1 | 910 | Resistor_SMD:R_1206_3216Metric
R67 | 1 | 47 | Resistor_SMD:R_0805_2012Metric
R69 | 1 | 12k | Resistor_SMD:R_0805_2012Metric
R70 | 1 | 200 | Resistor_SMD:R_0805_2012Metric
R77 | 1 | 100k | Resistor_SMD:R_0805_2012Metric
R80 | 1 | 7.5k | Resistor_SMD:R_1206_3216Metric
R85 | 1 | 7.5k | Resistor_SMD:R_0805_2012Metric
R104 | 1 | 47k | Resistor_SMD:R_1206_3216Metric
TH1 | 1 | 10k | Resistor_SMD:R_0603_1608Metric | https://product.tdk.com/system/files/dam/doc/product/sensor/ntc/chip-ntc-thermistor/data_sheet/datasheet_ntcgs163jf103ft7.pdf | NTCGS163JF103FT7
X1 | 1 | LM1881 | Package_DIP:DIP-8_W7.62mm | https://www.ti.com/lit/ds/symlink/lm1881.pdf

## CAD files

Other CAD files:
downloads/video_integrated_PCB3_bottom_simplified.dxf
downloads/video_integrated_PCB3_top_simplified.dxf

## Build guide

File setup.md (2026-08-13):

# Installation and Setup
<br>

## Preparing the Board
* After PCBA assembly, it's a good idea to set the potentiometers to rough nominal positions to get a good image, prior to installation and first startup. Experimentally, I've found that setting the blue and green gain trim pots so that the low side to wiper resistance is about 600 ohms is a good starting point. For red, this is around 450 ohms. These values can be measured in-circuit (no need to do it prior to soldering the pots onto the board) as the adjustment is made. As will be discussed below, the RGB gain adjustments can also be done live when the system is running.<br><br>
* See the Fabrication section for details on installing sockets into the analog board. I'll assume here that this has been completed.<br><br>
* One other detail related to preparation of the analog board is that film capacitors CF4 and CL36 (see the image below) either need to be removed or bent over. These caps will otherwise interfere with the colorclassic_video_processor board, and working around them with a reduced board outline would have been too constraining. These caps serve no purpose with the XC1186B removed, so there's no harm in bending them or fully removing them. I've simply bent mine over in case I ever need them in the future.<br><br>
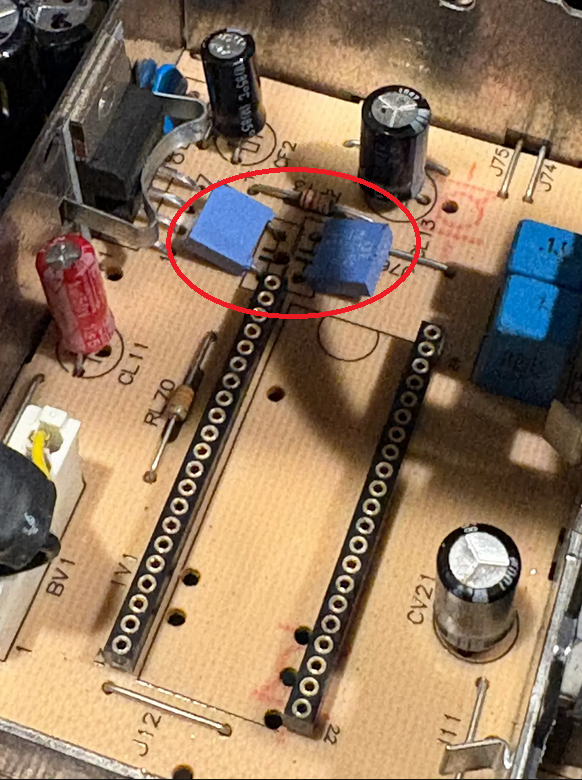
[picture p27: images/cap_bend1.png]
bend

<br><br>
* When installing the PCBA in the sockets, press firmly on all sides of the board, trying to keep it relatively level at all times. Of course, be careful not to apply too much force locally to any single component.<br><br>

## Startup
* When running the system for the first few times, it's convenient to run without the top of the video cage re-installed. This way, the PCBA can be pulled in and out if necessary, and the trim pots can be adjusted. There might be a very slight but noticeable vertical artifact line in the image in this state (corresponding to the negative edge of the horizontal drive pulse), but this will disappear with the cage top applied. Once all adjustments are completed and board works satisfactorily, I recommend replacing the top of the cage (as well as the bottom cover on the underside of the analog board, if it has not already been replaced).<br><br>
* As mentioned earlier, the RGB gain pots are located in a rear corner so that they're maximally accessible with the analog board fully installed, even with the system powered on. Adjustments can be made live to optimize the color balance to one's preference. Of course, always be careful when operating close to live CRT components.<br><br>
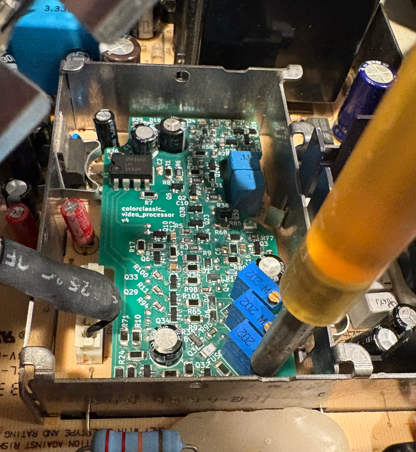
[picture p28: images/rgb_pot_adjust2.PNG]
rgb_pot

<br><br>

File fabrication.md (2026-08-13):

# Layout and Fabrication
<br>

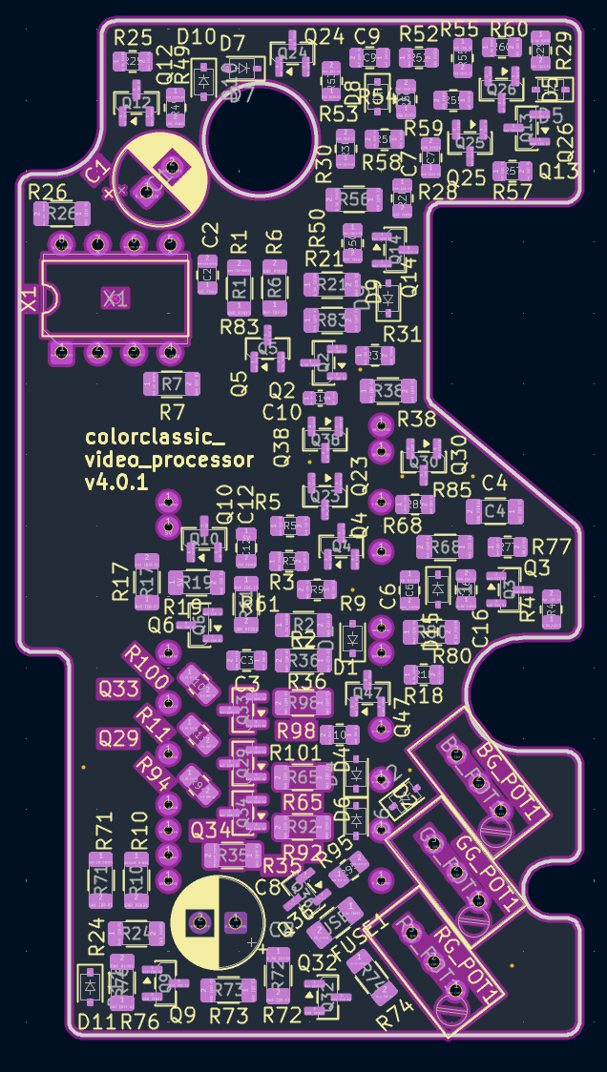
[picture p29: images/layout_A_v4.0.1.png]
layout_front

<br>

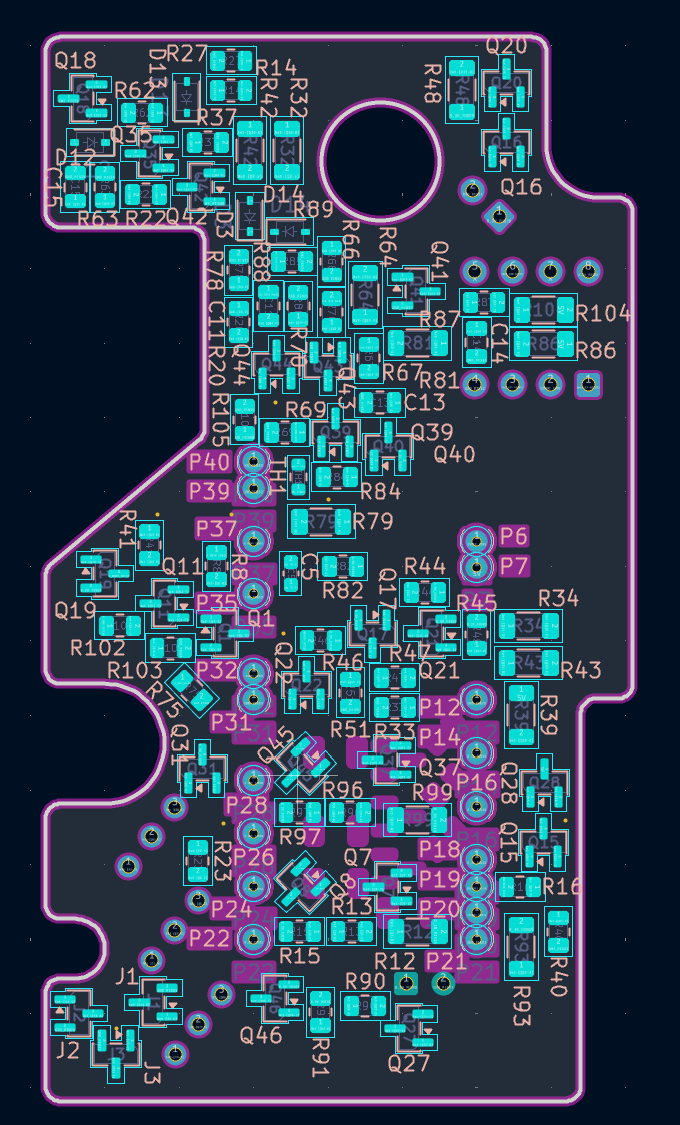
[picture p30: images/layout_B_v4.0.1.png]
layout_back

<br>

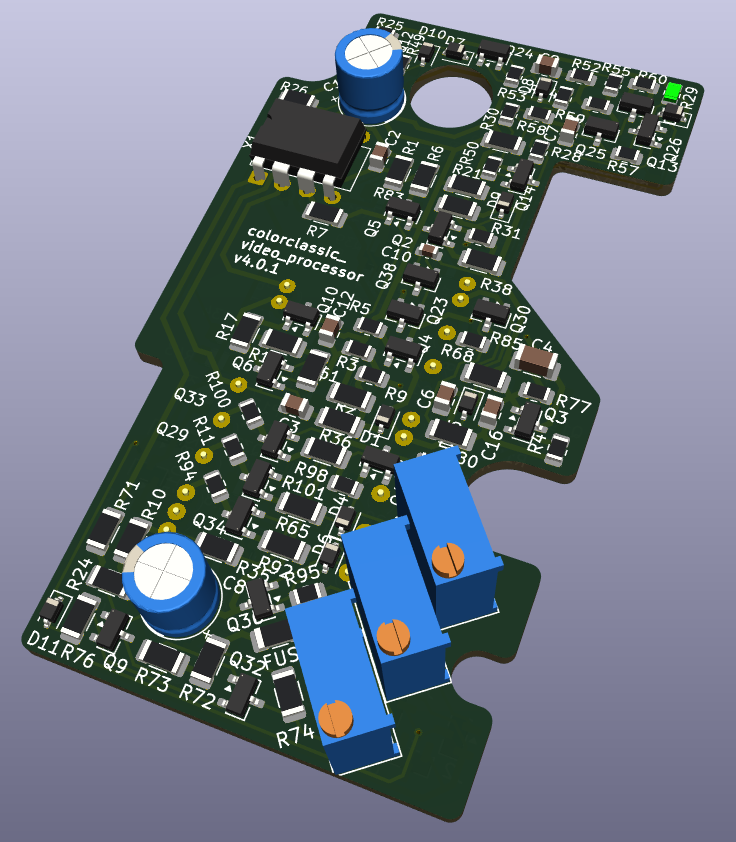
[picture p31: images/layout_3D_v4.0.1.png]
layout_3D

<br>

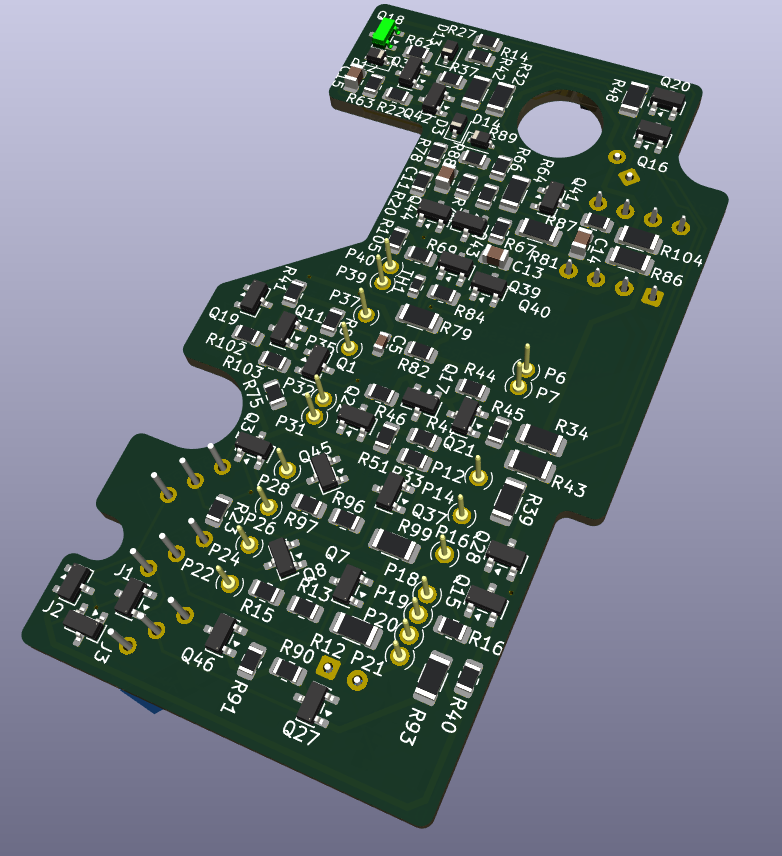
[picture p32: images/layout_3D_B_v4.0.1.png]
layout_3D_back

<br><br><br>

## Parts List
<br>
As mentioned in another section, the part identifiers have evolved organically along with the circuit design. The ordering doesn't have much relationship to the circuit layout at this point.<br><br>
Many of the components, such as resistors are commoditity SMD parts, so no part number is given, just specs. I would recommend using 1% fixed resistors whenever possible, as the cost is really quite negligible.<br><br>
Some of the capacitors absolutely require C0G dielectric for temperature stability and voltage insensitivity. A part number is explicity called out for all the capacitors. Other similar parts should work, as long C0G dielectric is used where specified.<br><br>
The BOM is too long to provide in a table on this page, so I've provided a CSV file here:<br>

[BOM](https://github.com/jonschultz/colorclassic_video_processor/blob/main/downloads/ccvp_v4.0.1.csv)
<br>

<br><br>

## Fabrication Details:
* Not all of the 42 pins of the original XC1186B footprint are utilized, as some of these simply connect to discrete components on the AB that I'm not using in my design. There are also sections that I haven't fully implemented, like horiztonal deflection shutdown for X-ray protection, making use of Pin 30.<br><br>
* The Mill-Max pins on the board could be directly soldered to the Color Classic's analog board after the XC1186B is desoldered an removed, but I highly recommend using a socketed connection instead. This will make debugging and rework much easier. I used two of the Preci-dip 317-87-121-41-005101 sockets, which are needed for the two rows of 21 pins locations. These use the correct 1.78mm pitch of the XC1186B, and their pin diameters are compatible with the AB's through holes.<br><br>
* Some regions of the circuitry involve fairly high impedances, especially in the RGB pre-amp section. As such, even small current leakage from flux residue can reduce performance. It's important to wash away all flux residue after PCB assembly, if you are doing your own hand-assembly. The same applies the analog board after desoldering the XC1186B.<br><br>
* I've provided a zip file with the fabrication files (Gerbers and drill files) for v4.0.1, which can be directly uploaded to a PCB fab house like PCBWay. I've also provided a zipped archived set of KiCad design files. Everything here is provided under a Creative Commons license, allowing anyone to reuse/remix this work for non-commercial purposes.<br>
<a href="https://github.com/jonschultz/colorclassic_video_processor/">colorclassic_video_processor</a> © 2026 by <a href="https://github.com/jonschultz/colorclassic_video_processor/">Jonathan Schultz</a> is licensed under <a href="https://creativecommons.org/licenses/by-nc-sa/4.0/">CC BY-NC-SA 4.0</a>

[KiCad Design Files](https://github.com/jonschultz/colorclassic_video_processor/blob/main/downloads/ccvp_v4.0.1.zip)
<br>
[Gerber Files](https://github.com/jonschultz/colorclassic_video_processor/blob/main/downloads/ccvp_v4.0.1_gerber.zip)

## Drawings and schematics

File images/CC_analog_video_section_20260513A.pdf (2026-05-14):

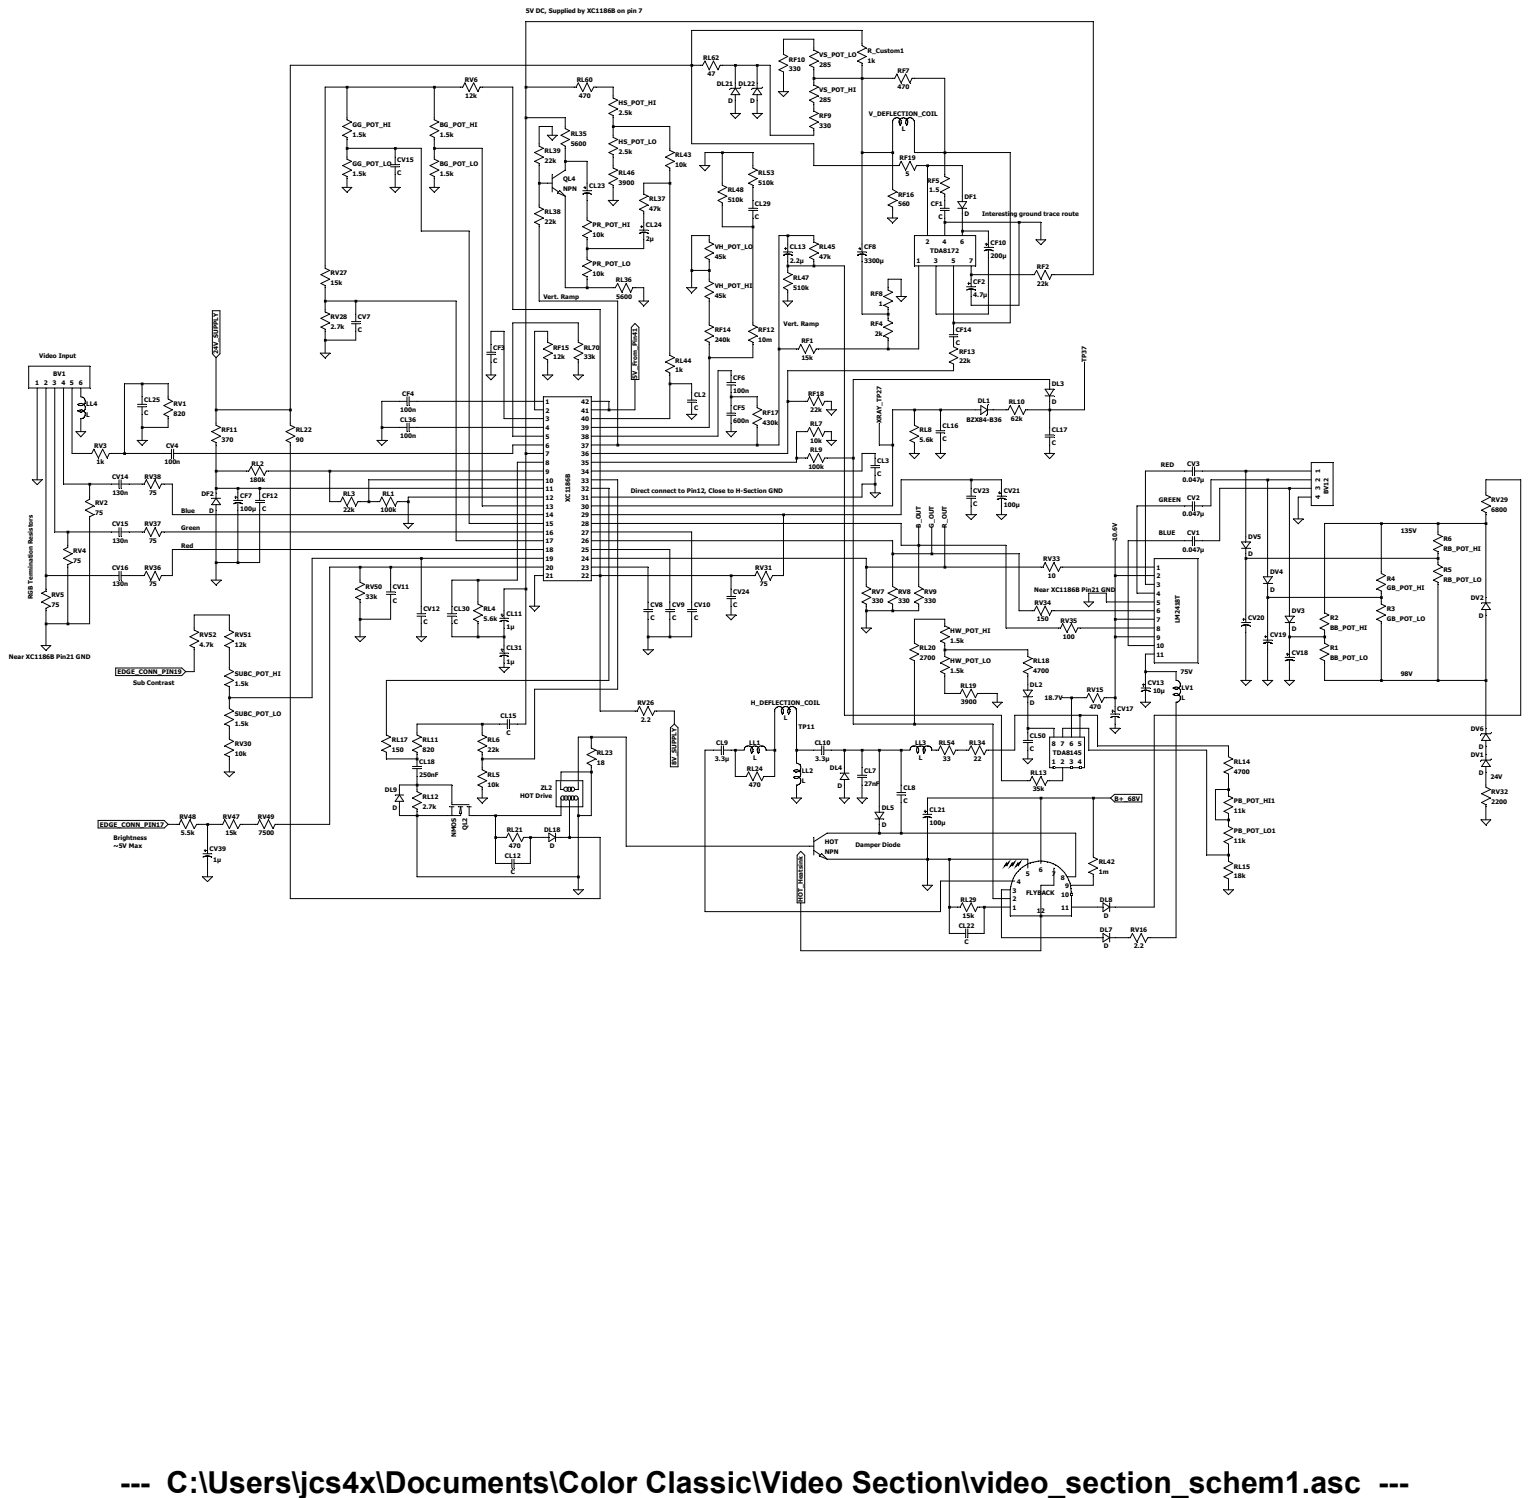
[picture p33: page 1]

5V DC, Supplied by XC1186B on pin 7

Interesting ground trace route

Video Input RGB Termination Resistors

Direct connect to Pin12, Close to H-Section GND

--- C:\Users\jcs4x\Documents\Color Classic\Video Section\video_section_schem1.asc ---

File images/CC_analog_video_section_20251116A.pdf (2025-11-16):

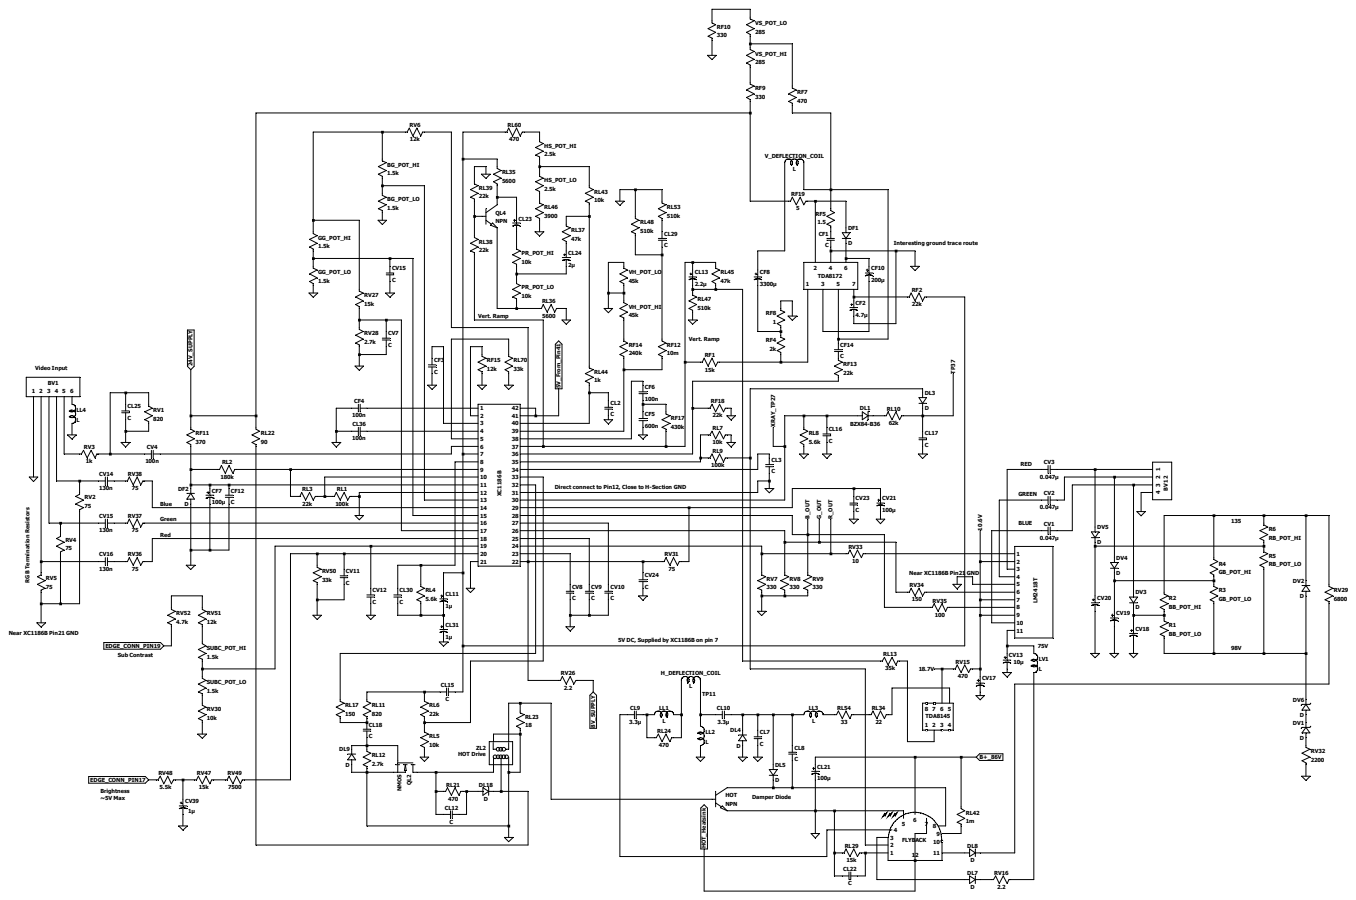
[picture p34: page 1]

Interesting ground trace route

Video Input RGB Termination Resistors

Direct connect to Pin12, Close to H-Section GND

5V DC, Supplied by XC1186B on pin 7

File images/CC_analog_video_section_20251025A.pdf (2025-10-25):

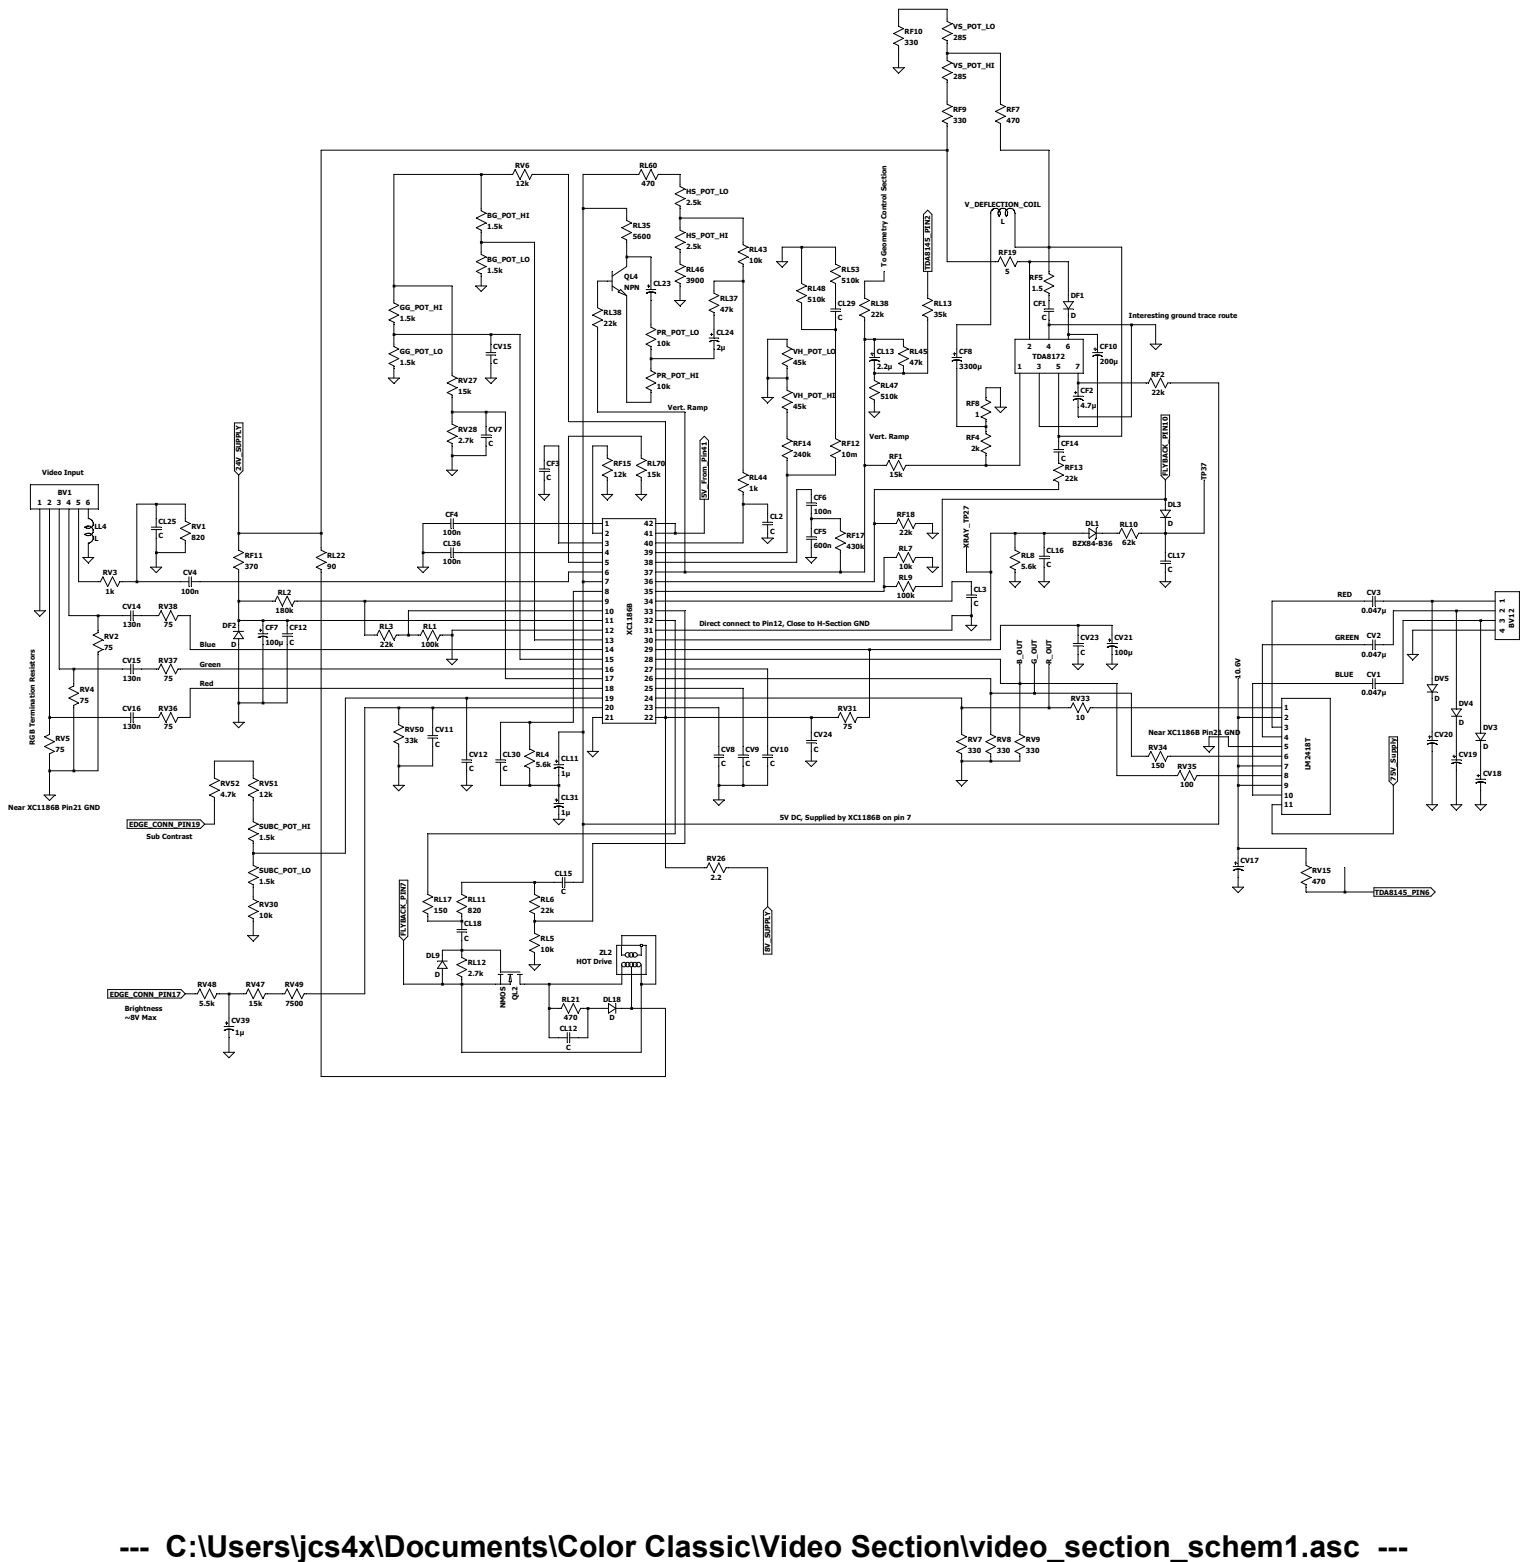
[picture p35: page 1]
42 LM²⁴¹⁸T; BZX84-B36; QL2 NMOS; TDA8172; VH_POT_HI 45k; VH_POT_LO 45k; HS_POT_HI 2.5k; HS_POT_LO 2.5k; PR_POT_HI 10k; PR_POT_LO 10k; BG_POT_LO 1.5k; BG_POT_HI 1.5k; GG_POT_LO 1.5k; GG_POT_HI 1.5k; V_DEFLECTION_COIL; VS_POT_HI 285; VS_POT_LO 285; SUBC_POT_LO 1.5k; SUBC_POT_HI 1.5k; QL4 NPN; CV20 FLYBACK_PIN¹⁰; TP37 XRAY_TP27; B_OUT; G_OUT; R_OUT 8V_SUPPLY FLYBACK_PIN⁷; TDA8145_PIN² 24V_SUPPLY; TDA8145_PIN6 ¹⁰.6V; EDGE_CONN_PIN19; EDGE_CONN_PIN17; 5V_From_Pin41; 75V_Supply; HOT Drive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

Interesting ground trace route

Video Input RGB Termination Resistors

Direct connect to Pin12, Close to H-Section GND

5V DC, Supplied by XC1186B on pin 7

--- C:\Users\jcs4x\Documents\Color Classic\Video Section\video_section_schem1.asc ---

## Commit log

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2025-11-02 Revise horizontal section and signal chain details
    Updated the description of the horizontal section and signal chain for clarity and consistency.
2025-11-02 Enhance explanation of threshold logic BJT and output pulse
    Added details about the signal application to Pin 32 and its impact on the horizontal scan phase.
2025-11-03 Refine horizontal section and signal chain details
    Updated the horizontal section description and signal chain details in the sub_circuits.md file.
2025-11-03 Update README with PCB images and descriptions
    Added images and descriptions of the PCB assembly and installation.
2025-11-03 Revise README with detailed project information
    Updated project description and added a link to the analog board schematic.
2025-11-06 Revise sub_circuits.md for clarity and detail
    Updated the description of the horizontal circuitry and considerations for improved clarity and detail.
2025-11-06 Document considerations for horizontal circuitry
    Added considerations for horizontal circuitry design and supply voltage.
2026-04-04 Revise README with project details and schematic links
    Updated project description and added links to latest schematics.
2026-04-05 Revise circuitry descriptions and component details
    Updated the descriptions of the horizontal and vertical sections of the circuitry, including changes to component values and configurations. Adjusted the explanations for the signal processing and ti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
2026-04-05 Document RGB Preamp functionality in sub_circuits.md
    Added RGB Preamp section detailing the function and implementation of the XC1186B RGB preamp, including amplifier stages and clamping circuitry.
2026-04-05 Fix formatting and improve clarity in signal chain section
2026-04-05 Revise signal chain description in sub_circuits.md
    Updated the description of the signal chain for clarity and consistency, ensuring all technical details are accurately represented.
2026-04-05 Update schematic 20260405A with adjustments
    Removed coarse adjustment pot for vertical size and replaced it with fixed resistors.
2026-04-07 Fix duplicate sentence on Schottky diodes in considerations
    Corrected a repeated sentence about Schottky diodes and their characteristics.
2026-04-11 Update RGB signal chain description and add scope shot
    Clarified signal chain description and added scope shot details for better understanding of RGB signal processing.
2026-05-13 Revise change log for schematic updates
    Updated change log with new schematic revisions and detailed descriptions of modifications, including the introduction of 'Warp Compensation' and adjustments to various circuit components for improved performance.
2026-05-14 Clarify PCB assembly description in README
    Removed mention of bodge wires and rework in the PCB description for clarity.
2026-05-14 Refactor README to eliminate redundancy
    Removed duplicate project description and updated schematic link.
2026-05-14 Add links to PCB outline and trace DXF files
2026-05-16 Enhance fabrication document with via graphic reference
    Added a graphic reference for via locations and clarified the method for creating vias using wire loops.
2026-05-17 Update setup.md with installation and adjustment details
    Added additional notes on installation and adjustments for the analog board, including details on handling film capacitors and adjusting the warp (SKEW_POT).
2026-05-17 Update fabrication details for PCB design and components
2026-05-17 Add bare board image to fabrication documentation
    Added an image of the bare board to the documentation.
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2026-05-17 Revise sub-circuits documentation for clarity
    Updated text for clarity and consistency in the sub-circuits documentation, including detailed explanations of circuitry behavior and component choices.
2026-05-24 Revise change log for schematic updates
    Updated change log for schematic revisions, including modifications to component values and descriptions of circuit capabilities.
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2026-06-20 Update future.md with design changes and progress
    Document updates on horizontal drive timing architecture and circuit improvements.
2026-06-20 Revise future.md with latest development updates
    Updated the current development status with recent progress on horizontal drive timing architecture and phase correction improvements.
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2026-07-26 Revise README for project details and version updates
    Updated project description and current capabilities for clarity and accuracy.
2026-07-26 Add links to fabrication files for v4.0.1
    Updated the fabrication details to include links to the KiCad design files and Gerber files for v4.0.1.
2026-07-26 Update BOM reference in fabrication.md
    Added a link to the BOM CSV file for better accessibility.
2026-07-26 Update fabrication.md with BOM link
    Added a link to the BOM CSV file for reference.
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2026-07-26 Include link to KiCad design files in fabrication.md
    Added a link to KiCad design files for reference.
2026-07-26 Change link to BOM CSV file
    Updated the link to the BOM CSV file in the documentation.
2026-07-26 Refine setup instructions for analog board preparation
    Removed unnecessary line breaks and improved clarity in the setup instructions.
2026-08-19 Fix image path for VGA connector in future.md
2026-10-21 Update development history with v4.2.1 details
    Added entry for v4.2.1 PCB fab order and minor updates.
2026-11-07 Revise sub-circuits documentation for V4.2.2
    Updated the sub-circuits documentation to reflect changes in component specifications and design improvements for version 4.2.2.
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2026-11-07 Update fabrication file links to v4.2.2
    Updated links to the latest KiCad design and Gerber files for version 4.2.2.
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2026-11-07 Update VGA output section in setup.md
    Clarified details on VGA output capability and signal pin connections for v4.2.2.
2026-11-07 Enhance setup.md with VGA output details for v4.2.2
    Expanded details on VGA output capability in v4.2.2, including installation notes and signal pin information.
2026-11-07 Enhance VGA output documentation for v4.2.2
    Updated the section on VGA output capability in version 4.2.2, including details on pin connections and image quality recommendations.
